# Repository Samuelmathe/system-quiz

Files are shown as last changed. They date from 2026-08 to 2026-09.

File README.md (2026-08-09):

# DMX Quiz Project (Arduino + Python)

Ce dossier contient :
- des **sketches Arduino** (`.ino`)
- 2 **logiciels Python** (interfaces GUI) pour piloter/configurer le système via USB (port série)

## Contenu

- **Arduino**
  - `megaf.ino` : sketch pour Arduino MEGA (DMX + logique de jeu ; plus de radio directe, voir `rf_nano_bridge.ino`)
  - `rf_nano_bridge.ino` : sketch pour **RF-Nano** (Nano + nRF24 intégrés) — pont radio nRF24 ↔ série vers le Mega ; seule carte du système avec un module radio
  - `buzzer_nano_equipe.ino` : sketch pour Arduino NANO (équipe)
  - `nano_son_final.ino` : sketch pour Arduino NANO (son)
  - `nano_animateur_final.ino` : sketch pour Arduino NANO (animateur)

- **Python**
  - `configuration/config_final_30.py` : outil de configuration (équipes / DMX / sync MEGA)
  - `interface/interface_30eq.py` : interface “quiz board” (scores/buzz + série)
  - `diagnostics/quiz_logger.py` : logger de diagnostic (écoute passive d'un port série dédié, en parallèle du logiciel de score — voir [Diagnostics](#diagnostics-quiz_loggerpy))

**Modes d’utilisation (sans PC / PC+Mega / PC+nano son)** : voir [MODES.md](MODES.md).

## Prérequis

- Python 3.9+ recommandé
- Arduino IDE (ou PlatformIO) pour compiler/téléverser les `.ino`

## Installation Python

Depuis la racine du projet :

```bash
python3 -m pip install --user -r requirements.txt
```

## Lancer les logiciels Python

Depuis la racine du projet :

```bash
python3 configuration/config_final_30.py
python3 interface/interface_30eq.py
```

## Fichiers créés automatiquement (configs)

- `configuration/config_final_30.py` lit/écrit : `configuration/config_quiz_pro.json`
- `interface/interface_30eq.py` lit/écrit : `interface/quiz_board_config.json`

Ces fichiers JSON sont créés automatiquement **à côté de chaque script**, ce qui rend le projet plus simple à partager et lancer depuis n'importe quel dossier.

## Sons (interface)

`interface/interface_30eq.py` essaie de charger des sons depuis le dossier `sounds/` **à côté du script** :
- `buzz.mp3` (buzz général / fallback)
- `victoire.mp3` (bonne réponse)
- `echec.mp3` (mauvaise réponse)
- `equipe_1.mp3` → `equipe_30.mp3` (sons spécifiques par équipe, optionnels)

Le dossier `sounds/` doit être **à côté du script** (ou à côté de l’exécutable si tu as “packagé” l’app).
Exemple attendu :

```
interface/
  interface_30eq.py
  sounds/
    buzz.mp3
    victoire.mp3
    echec.mp3
    equipe_1.mp3
    ...
    equipe_30.mp3
```

Si `pygame` n’est pas dispo (ou si les fichiers sont absents), l’interface fonctionne, mais sans sons.

## Diagnostics (`quiz_logger.py`)

Outil séparé du logiciel de score : il écoute en **passif** un port série de diagnostic
(un adaptateur USB-TTL dédié, branché en parallèle sur `PC_SERIAL`/`Serial3` du Mega —
aucun conflit avec le logiciel de score, qui utilise son propre adaptateur).

Il affiche le flux en direct, enregistre le log complet dans un fichier horodaté, et
génère un fichier résumé (durée de session, nombre de buzz, freezes/silences détectés,
redémarrages Mega détectés) pratique à partager pour du support/diagnostic à distance.

```bash
python3 diagnostics/quiz_logger.py
```

Un exécutable Windows est aussi généré automatiquement par GitHub Actions à chaque
modification de ce fichier (voir l'onglet *Actions* du dépôt).

## Linux : accès au port série Arduino

Si tu as une erreur de permission sur `/dev/ttyACM0` ou `/dev/ttyUSB0` :

```bash
sudo usermod -aG dialout $USER
```

Puis **déconnexion/reconnexion** (ou redémarrage) pour que le groupe soit pris en compte.

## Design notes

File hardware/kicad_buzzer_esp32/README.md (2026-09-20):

# Schéma de départ — Buzzer équipe (secours ESP32 / ESP-NOW)

`buzzer_equipe_esp32.kicad_sch` : même méthode que `../kicad_buzzer_nano/` (généré à partir du BOM, vérifié avec `kicad-cli sch erc` réel). 6 composants, 6 nets.

## L'ESP32 est représenté comme un connecteur générique 4 broches

Il n'existe pas de symbole KiCad standard pour la carte exacte commandée (ESP32 DevKit V1/ESP32-DevKitC-32 — trop de variantes de brochage différentes selon les fabricants). **U1** représente donc uniquement les 4 signaux réellement câblés sur ce PCB vers le module ESP32, pas les ~30 broches physiques :

| Broche U1 | Signal ESP32 | Usage (voir `esp32_buzzer_equipe.ino`) |
|---|---|---|
| 1 | GPIO4 | Bouton buzz |
| 2 | GPIO13 | IN du module vibreur |
| 3 | 5V / VIN | Alimentation |
| 4 | GND | Masse |

GPIO2 (LED embarquée) n'apparaît pas : elle est **interne au module ESP32 lui-même**, rien à router sur ce PCB pour elle.

## Avertissements ERC (28 au total)

| Type | Nombre | Normal ? |
|---|---|---|
| `endpoint_off_grid` | 12 | Cosmétique, sans conséquence électrique |
| `pin_not_connected` | 7 | À vérifier une fois dans l'interface — voir note ci-dessous |
| `lib_symbol_mismatch` | 7 | Cosmétique — `Outils > Mettre à jour les symboles depuis la bibliothèque` |
| `label_dangling` | 1 | **Normal en pratique** — ton propre projet `quizkicad/mega` (fait à la main) en a **71** du même genre. Pas un signe d'erreur de génération. |
| `power_pin_not_driven` | 1 | **Normal en pratique** — présent aussi dans `quizkicad/mega` (3 occurrences). |

Le `label_dangling` et plusieurs `pin_not_connected` concernent le réseau `BAT_PLUS`/`GND` autour de `BT1`/`J2`/`U1` — les coordonnées calculées correspondent bien aux broches réelles (vérifié), mais KiCad les affiche quand même comme non connectés. Comme pour la version Nano : cliquez l'étiquette et redéplacez-la légèrement pour forcer la reconnexion visuelle, ou ignorez si vous câblez de toute façon ce réseau en dur au routage du PCB.

## Rappel important

`ESPNOW_WIFI_CHANNEL` dans `esp32_buzzer_equipe.ino` doit rester identique à celui du hub (`esp32/esp32_bridge_server.ino`) — sans rapport avec ce schéma, mais à ne pas oublier au premier flash de la carte.

## PCB : placement compact + pistes routées

`buzzer_equipe_esp32.kicad_pcb` : empreintes placées, **et pistes routées** — même pipeline que la carte Nano (Freerouting en CLI headless + réimport KiCad + `kicad-cli pcb drc` réel), voir `../kicad_buzzer_nano/README.md` pour le détail du pipeline.

**Changements suite à ta relecture** :
- **Le texte-guide en sérigraphie a été retiré** — repères de composants standards uniquement (U1L, U1R, SW1...).
- **Carte bien plus compacte** : ~68×101mm au lieu de 130×145mm.
- **v3 : réduite encore à 65×50mm exactement**, pour correspondre au boîtier déjà conçu. U1L/U1R (les deux barrettes du module ESP32, 49mm de long chacune) ont dû être **pivotées à 90°** pour tenir dans cette largeur — leur entraxe réel (22,86mm) est inchangé, seule l'orientation sur la carte change, ça ne modifie rien au câblage ni au module qui s'enfiche dessus. Les 6 petits connecteurs (SW1, SW2, BATLED, J3, J2, BT1) sont serrés sur une seule rangée en bas de la carte, J2/J3 également pivotés à 90° pour gagner de la place en hauteur.
- Pas de keepout sur cette carte : pas de nRF24 ici, l'ESP-NOW utilise l'antenne intégrée à la puce ESP32 elle-même.
- **SW1, SW2, J2, J3 (connecteurs "fils volants") sont maintenant en CMS** (empreintes SMD), par choix explicite pour un assemblage machine (PCBA) chez le fabricant. Même numérotation de broche qu'avant. **Restent traversants** : U1L/U1R (le module ESP32 s'enfiche dessus) et **BT1**.
- **BT1 (batterie) est un vrai connecteur JST-PH** (`JST_PH_B2B-PH-K`, mâle, traversant) — même raisonnement que la carte Nano (voir son README) : la batterie a déjà une prise femelle sertie sur ses fils, et ce connecteur encaisse des cycles de branchement/débranchement qu'un pad CMS ne supporterait pas. Broche 1 = + (rouge), broche 2 = − (noir) — **vérifie la polarité sur ta batterie reçue**.
- **Nouveau : BATLED**, connecteur 2 broches (CMS) pour le module indicateur de niveau de batterie (4 LED) — même composant/câblage que la carte Nano, voir son README pour le détail.

**U1 est un vrai port femelle** : deux barrettes `PinSocket_1x19` (U1L/U1R, 38 broches au total, entraxe 22,86mm — la dimension déjà notée dans `hardware/boitier_buzzer_equipe.scad` pour ce module). Seules 4 des 38 positions physiques sont câblées (GPIO4, GPIO13, VIN, GND) ; les 34 autres sont présentes uniquement pour que le module s'enfiche mécaniquement.

⚠️ **Brochage à vérifier sur le module reçu avant de souder** : contrairement à la carte hub (ESP32 DevKit V1 30 broches, un modèle de référence unique et confirmé par toi), les cartes ESP32 38 broches existent en plusieurs variantes de brochage chez différents fabricants. J'ai utilisé la disposition générique la plus courante ("style NodeMCU-32S", vérifiée sur https://www.espboards.dev/esp32/esp32-38pin-devkit-generic/) : broche réelle 32 = GPIO4, broche 15 = GPIO13, broche 19 = VIN, broche 14 = GND. **Compare ces numéros avec les repères imprimés sur ton module avant de souder** — si ça ne correspond pas, il suffit de déplacer les 4 fils, la carte elle-même n'a pas besoin d'être refaite.

- Aperçu : `apercu_pcb.png`.

**Résultat (v3, 65×50mm)** : **0 violation de clearance, 0 élément non connecté**. DRC final : 19 avertissements, tous cosmétiques — `lib_footprint_mismatch` (5, comme d'habitude), `silk_overlap` (1, texte de référence U1R qui chevauche légèrement son propre contour après la rotation à 90°), et `silk_over_copper` (13, des pistes routées passent juste sous la sérigraphie de J2/J3 — carte très dense, aucun impact électrique, juste un risque que l'encre sérigraphie ne s'imprime pas parfaitement à ces endroits précis). Un `track_dangling` initial (résidu d'autorouter, un stub B.Cu redondant en doublon d'un chemin déjà assuré côté F.Cu) identifié et supprimé après vérification de la topologie réelle — **0 track_dangling restant**.

## Prochaine étape

Ouvre le PCB dans KiCad, relis le routage à l'œil, puis passe aux fichiers de fabrication (Gerbers).

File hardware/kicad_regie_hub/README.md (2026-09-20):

# Schéma de départ — Régie/Hub (adaptateur Mega + ESP32 + nRF24)

`regie_hub_mega_esp32.kicad_sch` : même méthode que les deux cartes buzzer (généré, **vérifié avec `kicad-cli sch erc` réel**). 11 composants, 14 nets.

## ⚠️ Correction : broches VCC/GND du nRF24 inversées, module PA+LNA (2×4)

Même correction que sur la carte buzzer Nano (voir `../kicad_buzzer_nano/README.md` pour le détail complet) : **J_NRF avait VCC en broche 1 et GND en broche 2 — inversé par rapport à la vraie numérotation** (broche 1 = GND, broche 2 = VCC), vérifié contre 3 sources indépendantes. Corrigé partout. Ton module confirmé étant un **nRF24L01+PA+LNA** (2×4 broches), l'empreinte J_NRF est passée de `PinSocket_1x08` à `PinHeader_2x04` (connecteur **mâle** — le module a lui-même des ports femelles, donc c'est la carte qui doit porter les broches mâles).

## Ce que cette carte est (et n'est pas)

**Ce n'est PAS un shield Mega complet.** Le shield DMX (`quizkicad/mega`, projet séparé, non touché) s'empile déjà directement sur la Mega. Cette carte-ci est un **petit adaptateur** qui porte l'ESP32 + le nRF24 + l'électronique entre les deux, relié à la Mega par seulement **6 fils** :

| Broche J_MEGA | Signal | Vers la Mega |
|---|---|---|
| 1 | TX2 (5V) | Mega pin 16 |
| 2 | RX2 | Mega pin 17 |
| 3 | TX1 (5V) | Mega pin 18 |
| 4 | RX1 | Mega pin 19 |
| 5 | 5V | Sortie régulateur onboard de la Mega |
| 6 | GND | Masse commune |

⚠️ **[FIX] Broches 3/4 déplacées de Mega Serial3 (pins 14/15) vers Mega Serial1 (pins 18/19)** : en vérifiant le câblage réel avec Samuel, Serial3 était déjà utilisé par le shield DMX (mal aiguillé côté firmware, corrigé dans `megaf.ino`) et doit rester dédié au câble TTL PC (scripts Python) comme lien de secours simultané au WiFi. Serial1 était complètement libre sur la Mega — voir `megaf.ino` et `esp32/esp32_bridge_server.ino` pour le détail complet.

**Alimentation** : pas de batterie sur cette carte — confirmé par toi : "on branche le mega [secteur] mais le reste des modules sera alimenté [par lui]". Le 5V vient du régulateur déjà présent sur la Mega.

## Pourquoi un pont diviseur et pas un module convertisseur de niveau logique

Tu as mentionné un "convertisseur logique" entre les RX/TX de la Mega et de l'ESP32. J'ai utilisé le **pont diviseur 1kΩ/2kΩ** à la place d'un module dédié — ce n'est pas un raccourci, c'est la solution **déjà documentée et déjà validée sur ce projet** (`cl.md` section 3.3, schéma dans `docs/APK_HYBRIDE_GUIDE.md`) pour exactement ces deux liaisons série. Réutiliser une solution qui marche déjà coûte moins cher et évite d'introduire une dépendance à un nouveau module non testé sur ce projet.

- **R1/R2** : diviseur sur Mega TX2 (5V) → ESP32 RX1 (3,3V) — lien Jeu.
- **R3/R4** : diviseur sur Mega TX1 (5V) → ESP32 RX2 (3,3V) — lien Config EEPROM (déplacé depuis TX3, voir note ci-dessus).
- **Pas de diviseur dans l'autre sens** (ESP32 TX → Mega RX) : déjà documenté que le 3,3V est lu comme HIGH par les entrées 5V de la Mega, connexion directe.

## Pourquoi un régulateur dédié au nRF24 (pas le 3V3 de l'ESP32)

Demandé : "un régulateur pour esp32" + "tout ce qui va avec ces composants pour un meilleur rendement". Plutôt que d'alimenter le nRF24 depuis la broche 3V3 embarquée de l'ESP32 (qui partage déjà la charge du Wi-Fi — creux de tension possible, cause connue d'instabilité nRF24, historique documenté sur ce projet), **U_REG** est un module régulateur 3,3V dédié rien que pour le nRF24, avec son propre découplage (C2, C3 — le condensateur 10-100µF déjà exigé par `cl.md` pour le nRF24).

## Avertissements ERC (36 au total)

Même profil que les deux cartes buzzer, déjà expliqué en détail dans `../kicad_buzzer_nano/README.md` — normal en pratique KiCad (comparé contre `quizkicad/mega`, ton propre projet fait à la main) :

| Type | Nombre | Normal ? |
|---|---|---|
| `endpoint_off_grid` | 20 | Cosmétique |
| `lib_symbol_mismatch` | 9 | Cosmétique — `Outils > Mettre à jour les symboles depuis la bibliothèque` |
| `pin_not_connected` | 4 | 2 attendus (3V3 onboard ESP32 et IRQ nRF24, non utilisés — no-connect posé), 2 liés au réseau GND (nuance ERC normale, voir README buzzer) |
| `no_connect_dangling` | 2 | Marqueurs "pas de connexion" légèrement décalés — à recaler d'un clic |
| `power_pin_not_driven` | 1 | Normal sur un réseau GND (également présent dans `quizkicad/mega`) |

## PCB : placement compact + pistes routées

`regie_hub_mega_esp32.kicad_pcb` : empreintes placées, **et pistes routées** — même pipeline que les deux cartes buzzer (Freerouting en CLI headless + réimport KiCad + `kicad-cli pcb drc` réel), voir `../kicad_buzzer_nano/README.md` pour le détail (y compris le mécanisme de keepout, identique ici).

**Changements suite à ta relecture** :
- **Le texte-guide en sérigraphie a été retiré** — repères de composants standards uniquement (J_MEGA, U_ESP32L/R, J_NRF, U_REG, R1-R4, C1-C3), pas de paragraphe d'instructions gravé sur la carte.
- **Carte bien plus compacte** : ~137×85mm au lieu de 185×145mm.
- **C3 (découplage nRF24) encore rapproché de J_NRF** (~12mm, contre 25mm dans la toute première version).
- **Zone sans cuivre sous le nRF24** : même mécanisme keepout que la carte Nano (voir son README pour le détail de la vérification), placé en presqu'île contre le bord droit pour ne bloquer aucun chemin de routage.
- **U_ESP32 est un vrai port femelle** : deux barrettes `PinSocket_1x15` (U_ESP32L/R, 30 broches, entraxe 15,24mm). Seules 11 des 30 positions physiques sont câblées ; les 19 autres sont présentes pour que le module s'enfiche mécaniquement. Brochage : **DOIT ESP32 DevKit V1, 30 broches** — exactement le modèle confirmé commandé, design de référence unique et bien plus standardisé que les clones 38 broches (vérifié sur https://www.espboards.dev/esp32/esp32doit-devkit-v1/).
- **J_NRF (nRF24) est un connecteur MÂLE 2×4** (`PinHeader_2x04`) — le module a des ports femelles dessus, donc la carte porte les broches mâles. 1=GND, 2=VCC, puis CE/CSN/SCK/MOSI/MISO/IRQ. ⚠️ **Vérifie les repères sur ton module avant de souder**, aucun standard universel pour les variantes PA+LNA.
- **R1-R4 et C1-C3 sont maintenant en CMS** (`R_0805`/`C_0805`), par choix explicite pour un assemblage machine (PCBA) chez le fabricant. Même numérotation de broche qu'avant. **Restent traversants** : J_MEGA, U_ESP32L/R et J_NRF (connecteurs de liaison/modules enfichables, pas adaptés au CMS).
- Aperçu : `apercu_pcb.png`.

**Résultat** : 78 connexions (14 nets), **0 violation de clearance, 0 élément non connecté**, 5 vias placées, keepout respecté (0 piste dedans, vérifié par script). DRC final : 12 avertissements, tous `lib_footprint_mismatch` (cosmétique). 4 `track_dangling` initiaux (résidus d'autorouter) identifiés et supprimés après vérification de la topologie réelle — **0 track_dangling restant**.

**C3 (découplage nRF24) rapproché de J_NRF** : le placement initial mettait C3 à 25mm de J_NRF (net `NRF_VCC_DEDIE`, qui relie aussi C2 et U_REG — ce n'est pas un simple lien à 2 broches). Trop loin pour un découplage propre à 2,4GHz. C3 a été repositionné à 12mm de J_NRF (`(152,20)` au lieu de `(165,20)`) et la carte entièrement re-routée : la piste J_NRF↔C3 est maintenant un tronçon direct et court, visible sur `apercu_pcb.png`.

## Prochaine étape

Ouvre le PCB dans KiCad et relis le routage à l'œil, puis passe aux fichiers de fabrication (Gerbers) — en particulier bien respecter les recommandations `cl.md` (VCC nRF24 en 3,3V uniquement jamais 5V, GND commun).

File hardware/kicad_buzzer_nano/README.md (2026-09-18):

# Schéma de départ — Buzzer équipe (Nano + nRF24)

`buzzer_equipe_nano.kicad_sch` : schéma généré à partir du BOM (`../../docs/BOM_BUZZER_EQUIPE.md`), **vérifié avec KiCad lui-même** (`kicad-cli sch erc`, format v9.0) — pas juste du texte non testé. 8 composants, 12 nets connectés (alimentation, bouton, module vibreur, nRF24 sur SPI matériel).

## ⚠️ Correction : broches VCC/GND du nRF24 inversées dans une version précédente

En répondant à ta question "le nrf24 c'est sur une ligne ?", j'ai vérifié le brochage du module nRF24 contre 3 sources indépendantes (components101.com, lastminuteengineers.com, doc générale nRF24L01+) et découvert que **J1 avait VCC en broche 1 et GND en broche 2 — c'est l'inverse** de la vraie numérotation (broche 1 = GND, broche 2 = VCC ; la broche 1 est d'ailleurs toujours la pastille carrée sur cette empreinte, et GND est documenté comme "identifiable par son marquage carré" sur les vrais modules). Corrigé partout : schéma, PCB, ce README. Si tu avais déjà commencé à câbler en suivant l'ancienne version, vérifie/corrige avant de mettre sous tension.

Tu as aussi confirmé que ton module est un **nRF24L01+PA+LNA** (longue portée, antenne externe) — ses 8 broches sont sur un connecteur **2×4**, pas 1×8 comme le module standard. L'empreinte J1 a été changée en conséquence (voir section PCB ci-dessous).

## Comment l'ouvrir

Ouvrez `buzzer_equipe_nano.kicad_sch` directement dans KiCad (File > Open). Aucun `.kicad_pro` fourni — KiCad vous proposera d'en créer un, acceptez.

## À faire en premier en l'ouvrant

L'ERC (`Inspecter > Vérification des règles électriques`) remonte 72 avertissements. La plupart sont normaux, mais trois méritent un coup d'œil :

| Avertissement | Nombre | À faire |
|---|---|---|
| `pin_not_connected` | 30 | **Normal** — la plupart des broches du Nano (A0-A7, D0/D1/D3/D4/D6/D7/D8...) ne sont pas utilisées par ce boîtier. Ignorer, ou ajouter des drapeaux "Pas de connexion" si vous voulez un ERC propre. |
| `lib_symbol_mismatch` | 12 | Cosmétique — mes copies embarquées des symboles (GND, +3V3, Battery_Cell) diffèrent légèrement de la bibliothèque système. `Outils > Mettre à jour les symboles depuis la bibliothèque` règle ça en un clic. |
| `endpoint_off_grid` | 19 | Cosmétique — mes coordonnées calculées ne tombent pas toujours pile sur la grille par défaut de KiCad. Sans conséquence électrique, juste esthétique. |
| `label_dangling` | 3 | **Normal en pratique** — `BAT_PLUS`, `NRF_SCK`, `VCC_5V_SW` : l'étiquette semble pile sur la bonne broche (vérifié par calcul), KiCad la signale quand même comme non connectée. J'ai vérifié : **ton propre projet `quizkicad/mega`** (fait à la main dans KiCad, pas généré) a **71** avertissements du même genre — c'est une nuance ERC courante, pas un signe d'erreur de génération. Cliquez l'étiquette et redéplacez-la légèrement si vous voulez un ERC propre, sinon ignorez. |
| `no_connect_dangling` | 1 | Le marqueur "pas de connexion" sur la broche IRQ du module nRF24 (non utilisée par le firmware) est légèrement décalé — à recaler d'un clic sur la broche. |
| `power_pin_not_driven` / `pin_not_driven` | 4 + 3 | Également présent dans `quizkicad/mega` (3 occurrences de `power_pin_not_driven`) — nuance ERC normale sur les réseaux GND, pas un bug. |

## PCB : placement compact + pistes routées

`buzzer_equipe_nano.kicad_pcb` : empreintes placées, **et pistes routées** — 2 couches (F.Cu/B.Cu), autoroutées avec [Freerouting](https://freerouting.app/) (outil open source dédié, pas un routage "deviné" à la main par moi) puis réimportées dans KiCad, le tout vérifié avec `kicad-cli pcb drc` réel.

**Changements suite à ta relecture** :
- **Le texte-guide en sérigraphie a été retiré** — ça n'a pas sa place gravé sur un vrai circuit fabriqué. Il ne reste que les repères de composants standards (A1L, J1, C1...), comme sur n'importe quelle carte.
- **Carte bien plus compacte** : ~90×100mm au lieu de 125×145mm — composants resserrés, plus d'espace perdu.
- **C1 (découplage nRF24) déplacé juste à côté de J1** (~10-12mm au lieu de ~30mm) pour un découplage propre.
- **Zone sans cuivre sous le nRF24** : un keepout (pistes/vias/plans interdits, sur les deux couches F.Cu et B.Cu) couvre l'espace où le corps/l'antenne du module PA+LNA se trouve une fois enfiché — pour ne pas mettre de cuivre sous l'antenne. Positionné en "presqu'île" contre le bord droit de la carte (rien ne route à travers), pas collé sur J1 des deux côtés — une première tentative avait bloqué le routeur (8 pistes bloquées après 100+ passes) en enfermant le connecteur ; corrigé en laissant un côté totalement ouvert. **Vérifié réellement respecté par Freerouting** (pas juste accepté par KiCad) via un test dédié où un keepout bloquant délibérément le seul chemin entre 2 pastilles a fait router 0 piste par l'autorouteur — preuve qu'il n'était pas ignoré. Taille/position à vérifier/ajuster dans KiCad selon les dimensions réelles de ton module.
- **Le Nano est représenté par de vrais ports femelles** : deux barrettes `PinSocket_1x15` séparées (A1L = broches réelles 1-15, A1R = 16-30, espacées de 15,24mm comme sur un vrai Nano). Le Nano s'enfiche dessus, rien à souder sur le module lui-même.
- **J1 (nRF24) est un connecteur MÂLE 2×4** (`PinHeader_2x04`) — corrigé après que tu as précisé que le module lui-même a des ports femelles dessus, donc c'est la carte qui doit porter des broches mâles pour que le module s'enfiche dessus (logique inverse de A1L/A1R où c'est le Nano qui a des broches mâles). Broches 1=GND et 2=VCC sur la 1ère rangée, puis CE/CSN, SCK/MOSI, MISO/IRQ — ordre le plus souvent publié pour ce type de module, mais **aucun standard universel n'existe pour les variantes PA+LNA**. ⚠️ **Vérifie les repères imprimés sur ton module avant de souder.**
- **C1 et les connecteurs "fils volants" (SW1, SW2, J2, J3) sont maintenant en CMS** (empreintes SMD — `C_0805`, `PinSocket_..._SMD`), par choix explicite pour un assemblage machine (PCBA) chez le fabricant plutôt qu'à souder toi-même. Même numérotation de broche que les anciennes versions traversantes, rien d'autre n'a changé côté câblage. **Restent traversants** : A1L/A1R (Nano), J1 (nRF24) — headers de modules enfichables, pas adaptés au CMS — et **BT1**, voir point suivant.
- **BT1 (batterie) est maintenant un vrai connecteur JST-PH** (`JST_PH_B2B-PH-K`, mâle, traversant) au lieu de simples pastilles. Les batteries LiPo standards arrivent avec une prise JST-PH **femelle** déjà sertie sur leurs fils — la batterie se branche donc directement, rien à couper ni souder sur ses fils. Volontairement resté traversant (pas de version CMS) : ce connecteur encaisse des cycles répétés de branchement/débranchement, un pad CMS se décollerait à l'usage. Broche 1 = + (fil rouge), broche 2 = − (fil noir) — convention quasi universelle sur les batteries LiPo JST-PH, mais **vérifie la polarité sur ta batterie reçue** avant de brancher.
- **Nouveau : BATLED**, connecteur 2 broches (CMS) pour le module indicateur de niveau de batterie (4 LED, 25/50/75/100% — module "1S lithium battery capacity indicator", vérifié via handsontec.com). Branché directement en parallèle sur la batterie (même net que BT1 : broche 1 = B+, broche 2 = B-, ~5mA, toujours actif, pas de bouton). Voir `../../docs/BOM_BUZZER_EQUIPE.md`.
- Aperçu : `apercu_pcb.png`.

**Pipeline utilisé** : `pcbnew.ExportSpecctraDSN()` → `freerouting.jar` (mode CLI headless, `-mp 20`) → `pcbnew.ImportSpecctraSES()` → `kicad-cli pcb drc`. 74 connexions, **0 violation de clearance, 0 élément non connecté**, keepout respecté (0 piste dedans, vérifié par script).

**DRC final** : 5 avertissements, tous `lib_footprint_mismatch` (cosmétique, se corrige avec `Outils > Mettre à jour les empreintes depuis la bibliothèque`) — **0 track_dangling** dès le premier autoroutage cette fois.

**À vérifier toi-même avant fabrication** : largeur de piste/clearance par défaut de KiCad (pas de netclass personnalisée définie ici) — correcte pour du signal logique, mais à confirmer sur les nets d'alimentation (`VCC_5V_SW`, `GND`) selon le courant réel du vibreur.

## Prochaine étape

Ouvre `buzzer_equipe_nano.kicad_pcb` dans KiCad et relis le routage à l'œil (largeurs de piste, trajets) avant de passer aux fichiers de fabrication (Gerbers).

La version ESP32 (secours équipe) est dans `../kicad_buzzer_esp32/`, même méthode.

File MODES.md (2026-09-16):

# Trois modes d’utilisation — scores & sons (Quiz Board)

Ce document décrit les **trois configurations** possibles entre **Mega** (DMX + logique jeu, `megaf.ino`), **RF-Nano** (pont radio nRF24 ↔ série, `rf_nano_bridge.ino`), **nano son** (DFPlayer + radio), et le **logiciel** `interface/interface_30eq.py` (scores, sons PC, port série).

**Architecture radio (depuis la migration RF-Nano)** : le Mega n’a plus de module nRF24 branché directement (c’était la source d’un gel intermittent diagnostiqué en conditions réelles — connexion physique fragile vers la puce radio). Toute la réception nRF24 (équipes, animateur) et l’émission vers le nano son sont désormais assurées par une carte **RF-Nano** dédiée (Nano + nRF24 intégrés d’usine), reliée au Mega par une simple liaison série filaire (`Serial2`, 19200 bauds). Le Mega envoie/reçoit de simples lignes texte (`BUZZ:n`, `CMD:99`, `SON:200:n`…) au RF-Nano, qui traduit ça en paquets radio et inversement. Cette isolation protège la logique de jeu/DMX : même si le RF-Nano a un problème radio, le Mega continue de tourner.

**Règle matérielle (PC)** : le PC n’est branché en série qu’**à une seule carte à la fois** — soit la **Mega** (TTL / USB), soit le **nano son** (USB), **jamais les deux en même temps**. En mode 3, la Mega reste alimentée pour le DMX et le pilotage du RF-Nano, mais **sans** câble série vers le PC ; tout passe par le nano son (USB).

---

## Vue d’ensemble

| Mode | PC branché ? | Où vont les sons ? | Scores / interface |
|---|---|---|---|
| **1 — Sans PC** | Non | **DFPlayer** sur le nano son (carte SD, radio depuis la Mega) | Aucun logiciel |
| **2 — PC sur la Mega** | Oui, **port série TTL** de la Mega (`Serial3` / dongle USB‑UART) | **PC** (`sounds/*.mp3` via pygame) ; le nano son en salle est **optionnel** | Oui : buzz, points, VALIDER/FAUX, `CMD_SENT:` |
| **3 — PC sur le nano son** | Oui, **USB du nano son** | **PC** si mode **AUDIO_PC** (HP du DF débranché ou inutilisé) ; sinon **DFPlayer** si **AUDIO_DF** | Oui : le logiciel détecte le nano (`WHO` → `READY_NANO_SON`) |

---

## Mode 1 — Sans ordinateur

- La **Mega** gère la logique du jeu et le DMX ; elle reçoit les buzz/commandes animateur du **RF-Nano** par liaison série filaire, et lui envoie en retour les ordres **son** (`SON:200:n`, `SON:201:0`, `SON:202:0`) par la même liaison.
- Le **RF-Nano** retransmet ces ordres son en radio vers le **nano son** (pipe `00002`, payload `200` / `201` / `202`) — exactement le même paquet qu’avant, seule l’origine a changé (RF-Nano au lieu de la Mega directement).
- Le **nano son** joue les fichiers sur la **carte microSD** du DFPlayer (dossier `mp3/` sur la carte, ex. `0101.mp3` pour l’équipe 1, repli `0001.mp3`).
- **Pas** de fichier `equipe_1.mp3` sur le PC : tout passe par la convention **DF** (`0101` … `0130`).

---

## Mode 2 — PC branché sur la **Mega** (usage principal)

- Câble **USB‑UART** sur le port prévu pour le PC (souvent **TX3/RX3** de la Mega, voir commentaires dans `megaf.ino`).
- Le logiciel reçoit :
  - **`BUZZ:n`** quand une équipe buzze ;
  - **`CMD_SENT:RESET_ALL`** / **`CMD_SENT:RELANCE_PARTIEL`** quand l’animateur utilise les **boutons physiques** (nano animateur → Mega).
- Les **sons** passent par le dossier **`sounds/`** à côté du script : `buzz.mp3`, `victoire.mp3`, `echec.mp3`, et surtout **`equipe_1.mp3` … `equipe_30.mp3`** pour le buzz par équipe (priorité sur `buzz.mp3`).
- Le **nano son** peut rester en salle pour la même piste radio ; si le PC joue déjà les sons, évite d’avoir **deux** enceintes au même moment (ou baisse le volume d’un des deux chemins).

---

## Mode 3 — PC branché sur le **nano son** (USB)

- Dans le logiciel, choisis le **COM du nano son**. Après connexion, le programme envoie `WHO` : si la réponse contient **`READY_NANO_SON`**, le mode **nano** est actif.
- **Sons sur le PC (`AUDIO_PC`, défaut à la connexion)**  
  - Le nano **ne joue pas** sur le DF pour le buzz : il renvoie **`FWD_SON:200:N`** au PC pour que **pygame** joue (tu peux **débrancher le HP** du module DF pour n’entendre que le PC).
  - **Buzz** : `FWD_SON:200` = même traitement qu’un **`BUZZ:`** en mode 2 (état BUZZÉ, `equipe_N.mp3` si présent).
  - **Valider / refuser** (animateur → Mega → radio **201** / **202** → nano) : le nano envoie **`CMD_SENT:RESET_ALL`** / **`CMD_SENT:RELANCE_PARTIEL`** sur l’USB → **points et état** comme en mode 2, sans second câble vers la Mega.
- **Sons sur la carte SD (`AUDIO_DF`)**  
  - Décoche l’option « sons sur le PC » dans l’interface (ou envoi série `AUDIO_DF`) : le nano rejoue sur le **DFPlayer** comme en mode 1 ; fichiers **`mp3/0101.mp3`** … **`0130.mp3`** (équivalent `equipe_N` côté PC).

### Relais série depuis le PC (nano USB)

- Le logiciel peut envoyer **`RESET_ALL`** / **`RELANCE_PARTIEL`** au nano : le nano **réémet** les commandes radio vers les buzzers (même format que la Mega), utile si la Mega n’est **pas** sur le port PC mais toujours alimentée pour le DMX.

### Fichier de config

- `interface/quiz_board_config.json` (à côté du script) peut contenir entre autres :
  - **`points_au_buzz`** : points ajoutés au **moment du buzz** (0 = désactivé ; la bonne réponse ajoute encore la valeur « PTS » choisie dans l’interface).

---

## Correspondance des noms de fichiers (équipe 1, …)

| Équipe affichée | PC (`sounds/`) | Carte SD DFPlayer (`mp3/` sur la carte) |
|---|---|---|
| 1 | `equipe_1.mp3` | `0101.mp3` |
| N | `equipe_N.mp3` | `01NN.mp3` dans le dossier **`mp3/`** à la racine de la carte (ex. équipe 12 → `0112.mp3`). Le sketch utilise **`playMp3Folder(NNN)`** (commande 0x12) : **101** = fichier **`0101.mp3`**, **1** = **`0001.mp3`** — pas la commande `play()` qui suit l’ordre des fichiers sur la carte. |

La Mega envoie toujours le **numéro d’équipe 1…30** dans le payload radio **200** ; le nano son et le logiciel s’en servent pour choisir la piste ou le fichier.

---

## Fiabilité radio RF-Nano ↔ nano son (nRF24L01)

- **Même canal et adresse** : canal **108**, pipe **`00002`** pour les paquets `SonPayload`.
- **Buzz (200)** : le RF-Nano envoie une rafale de copies espacées de quelques ms (`envoyerSon()`/`updateRadioSonAsynchrone()` dans `rf_nano_bridge.ino`, portées depuis l’ancien `megaf.ino`) avec un **numéro de séquence** (`seq`) ; le nano met les paquets en **file** et **dédoublonne** par `cmd`+`team`+`seq`. DFPlayer : lecture **immédiate** si la piste équipe a déjà réussi une fois, sinon test erreur en fond.
- **Victoire / échec (201 / 202)** : même principe de rafale + dédoublonnage par `seq`.
- **Bonnes pratiques** : alimentation stable (condensateur près du nRF24), antennes correctes, distance raisonnable ; le **250 kbps** aide la portée.

## Fiabilité liaison Mega ↔ RF-Nano (série filaire)

- **`Serial2` sur la Mega (RX2=17, TX2=16)**, **19200 bauds**, GND commun obligatoire.
- Protocole texte simple, une commande par ligne : `BUZZ:n`, `CMD:99`/`CMD:88`, `SON:cmd:team`.
- Le RF-Nano dédoublonne aussi les commandes animateur par `seq` (évite qu’un accusé de réception radio perdu ne fasse rejouer plusieurs fois le son/flash pour un seul appui bouton).
- **Attention en développement** : les broches D0/D1 du RF-Nano sont partagées avec l’USB — débrancher le fil vers la Mega pour reprogrammer/déboguer via USB.

---

## Rappel câblage série (un seul port PC)

| Mode | Câble PC | Lignes reçues par le Quiz Board |
|---|---|---|
| **2 — Mega** | TTL Mega (Serial3) | `BUZZ:n`, `CMD_SENT:…` |
| **3 — Nano son** | USB nano son | `FWD_SON:200:n` (buzz), `CMD_SENT:…` (valider / faux via radio) |

Pas de branchement simultané Mega + nano son sur le même PC.

Pour lancer l’interface et les prérequis Python, voir le [README](README.md).

---

## Architecture de secours : équipes/animateur en ESP32 + ESP-NOW (sans nRF24)

**Uniquement pour l'architecture ESP32 hub** (`esp32/esp32_bridge_server.ino`, qui remplace le RF-Nano). Ne concerne pas `rf_nano_bridge.ino` / `megaf.ino`.

Historique de fiabilité nRF24 sur ce projet (gel intermittent diagnostiqué puis corrigé, bug de stress-test) : si un module nRF24 pose problème sur site, `esp32_buzzer_equipe.ino` et `esp32_animateur.ino` permettent de remplacer **un boîtier à la fois** (Nano+nRF24 → ESP32) sans toucher au hub ni aux autres boîtiers.

- **Un seul hub, deux transports simultanés** : le hub écoute nRF24 **et** ESP-NOW en même temps (`traiterMessageRadio()` dans `esp32_bridge_server.ino`), avec le **même** `RadioMsg{kind,value,seq}`, le **même** dédoublonnage par `seq`, la **même** fenêtre d'arbitrage de 50ms. Une équipe peut être en nRF24 pendant qu'une autre est en ESP-NOW.
- **Canal Wi-Fi fixe obligatoire** (`ESPNOW_WIFI_CHANNEL`, 6 par défaut) : à garder identique dans les **trois** fichiers (`esp32_bridge_server.ino`, `esp32_buzzer_equipe.ino`, `esp32_animateur.ino`). ESP-NOW exige que l'émetteur et le récepteur soient sur le même canal ; le hub le fixe via `WiFi.softAP(..., ESPNOW_WIFI_CHANNEL)`, changez cette valeur partout si le canal 6 est pollué sur le lieu de l'événement.
- **Broadcast, aucun appairage MAC** : plus simple à déployer en urgence (remplacer un boîtier en quelques secondes), au prix de l'absence d'accusé de réception matériel pour le broadcast (contrairement au nRF24 avec `setAutoAck`). Compensé par une **rafale de 4 copies** espacées de 12ms (`BURST_COUNT`/`BURST_GAP_MS`), même principe que la rafale son déjà utilisée dans ce projet — le hub dédoublonne par `seq`, donc les copies en trop ne créent jamais de buzz en double.
- **Consommation** : le Wi-Fi tire plus de courant que le nRF24 — moins d'autonomie si les boîtiers équipes sont sur pile plutôt que secteur/USB.

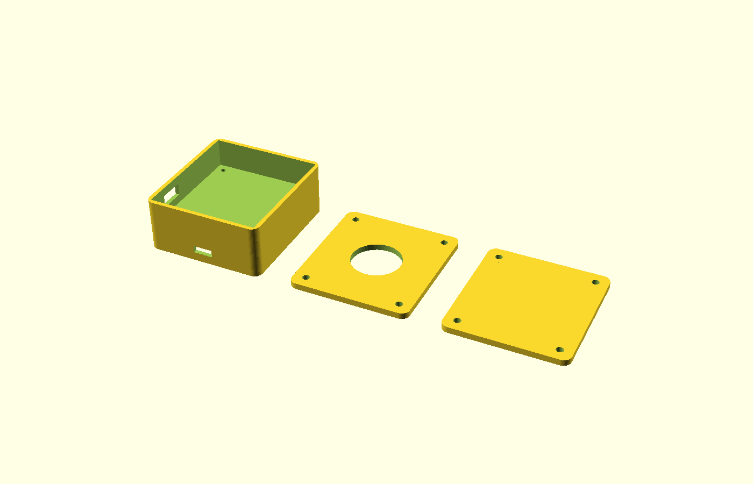
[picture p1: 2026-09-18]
hardware/apercu_variante_esp32.png

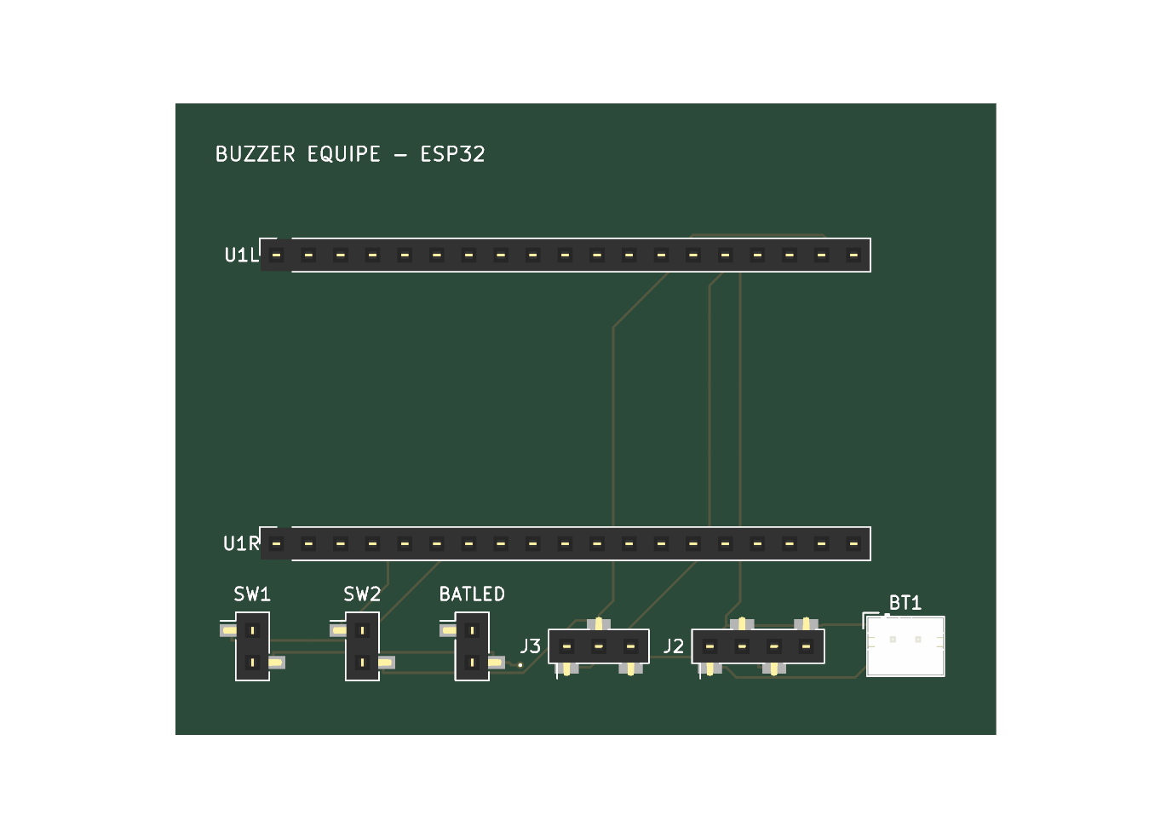
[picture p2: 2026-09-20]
hardware/kicad_buzzer_esp32/apercu_pcb.png

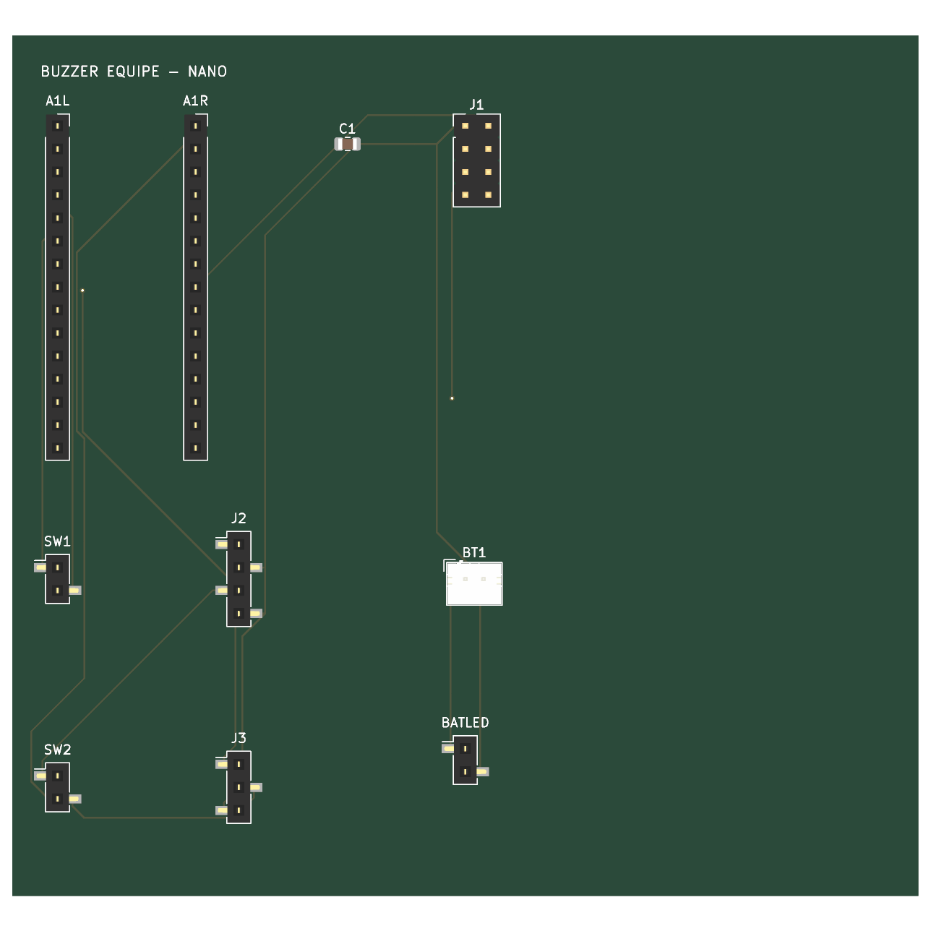
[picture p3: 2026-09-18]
hardware/kicad_buzzer_nano/apercu_pcb.png

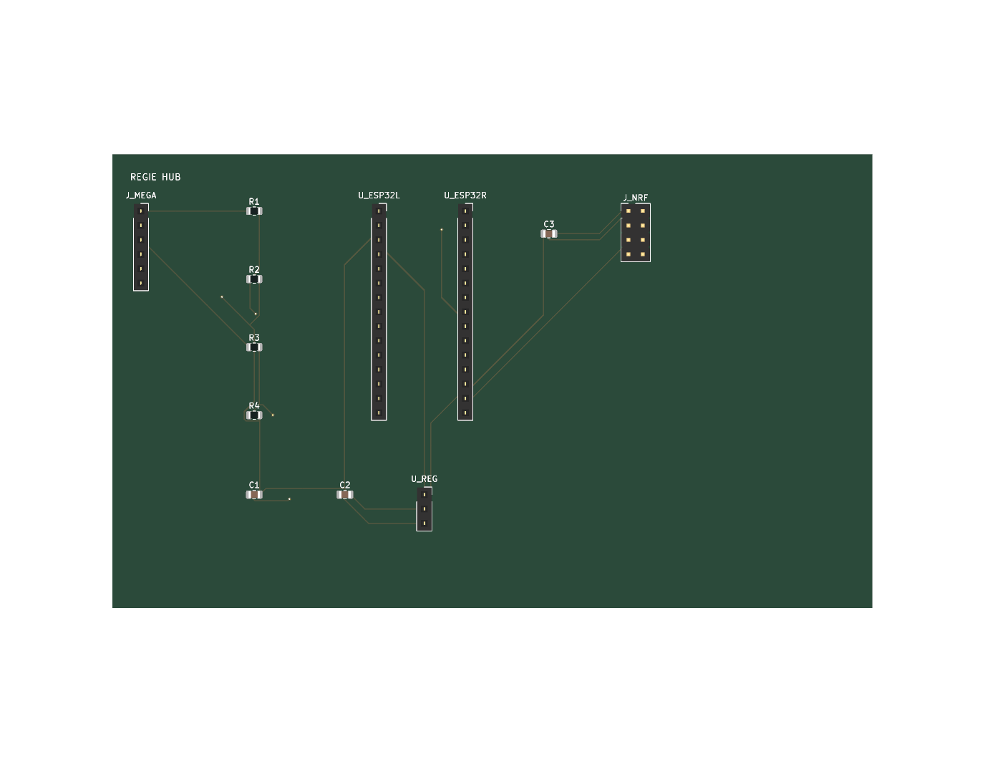
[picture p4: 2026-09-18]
hardware/kicad_regie_hub/apercu_pcb.png

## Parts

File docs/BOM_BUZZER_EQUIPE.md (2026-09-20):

# BOM & brochage — Boîtiers buzzer équipe (Nano+nRF24 et ESP32)

Référence pour démarrer le schéma KiCad des deux cartes. Basé sur le câblage déjà utilisé par le firmware (`buzzer_nano_equipe.ino` / `esp32_buzzer_equipe.ino`) — **aucun changement de code nécessaire**, seul le matériel autour est nouveau.

---

## ⚠️ Règle d'achat obligatoire : connecteur pré-câblé sur CHAQUE module

Les cartes PCBA sont livrées **directement au client**, pas à Samuel — il n'y a aucune étape intermédiaire où quelqu'un peut sertir/souder un connecteur avant l'envoi. Résultat : **le client ne doit jamais avoir besoin d'un fer à souder**, donc chaque module externe (pas juste la batterie) doit être acheté dans sa version **déjà équipée d'une prise compatible** sur ses fils, jamais en fils nus.

Chaque ligne concernée ci-dessous est marquée **🔌 connecteur pré-câblé obligatoire à l'achat**. Si un fournisseur ne propose vraiment aucune version pré-câblée pour l'un de ces éléments, c'est le seul point qui devra être signalé explicitement au client comme exception (fer à souder nécessaire) — à éviter autant que possible.

---

## Vibreur : module tout fait (IN / VCC / GND)

Confirmé : les vibreurs utilisés sont des **modules** à 3 broches (IN / VCC / GND), pas des moteurs nus. Le transistor de commande, la résistance de base et la diode de roue libre sont déjà intégrés sur le petit PCB du module — pas besoin de les reproduire sur la carte buzzer.

🔌 **Connecteur pré-câblé obligatoire à l'achat** — chercher une version du module avec un connecteur (JST/Dupont) déjà serti sur les 3 fils IN/VCC/GND, pas des fils nus à souder. Moins garanti que pour une batterie LiPo (module bon marché, souvent vendu en fils nus) — vérifier la fiche produit avant d'acheter, sinon prévoir de sertir soi-même avant tout envoi au client.

Câblage simplifié (identique sur les deux cartes) :

```
   GPIO (moteurPin) ──▶ IN
   5V (sortie boost) ──▶ VCC
   GND                ──▶ GND
```

`digitalWrite(moteurPin, HIGH/LOW)` pilote directement l'entrée IN du module, qui fait la commutation en interne. Si jamais vous passez un jour à un moteur nu (sans module), remettre un étage transistor+résistance+diode comme d'habitude sur ce type de charge inductive — mais ce n'est pas le cas ici.

---

## Bloc alimentation (commun aux deux cartes)

| Élément | Réf. type | Rôle |
|---|---|---|
| Batterie LiPo 1S 3,7V | Voir capacité par carte ci-dessous — 🔌 **connecteur JST-PH pré-serti obligatoire à l'achat** (standard sur la quasi-totalité des batteries hobby, filtrer sur ce critère) | Alimentation |
| Connecteur batterie | JST-PH 2 points, déjà présent côté PCB (BT1, soudé en usine PCBA) | Standard LiPo, polarité gardée |
| Module charge + protection | TP4056 **ou TP4057** (version améliorée, protection inversion de polarité en plus) + DW01A/FS8205A, **variante USB-C** — 🔌 connecteur pré-câblé à privilégier si disponible, sinon exception acceptée (module vendu en carte nue avec pastilles à souder, cas fréquent) | Charge + coupure basse tension automatique (~2,4-3,0V) + protection surcharge/court-circuit |
| Boost 5V | Module boost LiPo→5V (ex. base MT3608) — même remarque que ci-dessus, souvent vendu en carte nue | Tension stable 5V quelle que soit la charge de la batterie |

⚠️ **Le module charge (TP4056/TP4057) et le boost 5V sont deux fonctions distinctes** — certaines cartes combinées ("3 en 1") intègrent les deux sur le même petit PCB, d'autres non. **Vérifié pour le TP4057 en particulier : c'est une puce de charge pure, sans fonction boost.** Si ton module ne fait que charge+protection, il faut un second module boost séparé. Câblage dans ce cas :

```
Batterie (+/-) ──┬──▶ Module TP4057 (bornes BAT) — charge/protection, en parallèle
                  └──▶ Entrée du module boost — aussi en parallèle
Sortie du module boost (5V) ──▶ J2 broches 3/4 sur le PCB
```

Ça ne change rien au PCB (J2 reste 4 broches : BAT+, BAT-, 5V+, 5V-) — juste la façon dont les modules externes se câblent entre eux avant de rejoindre J2.
| Interrupteur | Glissière ou bouton-poussoir à verrouillage, sur la ligne 5V après le boost — 🔌 connecteur pré-câblé obligatoire à l'achat (fils avec Dupont/JST déjà sertis, pas de cosses nues) | Éteindre complètement entre deux events — sans lui l'autonomie 4-6h ne veut plus rien dire si le boîtier reste allumé par oubli |
| Indicateur niveau batterie | Module "1S lithium battery capacity indicator", 4 LED (25/50/75/100%) — 🔌 connecteur pré-câblé obligatoire à l'achat | Branché directement en parallèle sur la batterie (2 fils B+/B-, ~5mA, toujours actif, pas de bouton) — repère `BATLED` sur le PCB |

---

## Carte 1 — Nano + nRF24 (équipe, version principale)

### BOM

| Réf. | Composant | Note |
|---|---|---|
| U1 | Arduino Nano (ou compatible CH340) | Monté en carrier via headers femelles — pas besoin de graver un bootloader séparément |
| U2 | Module nRF24L01+ | **VCC en 3,3V uniquement, jamais 5V** |
| C1 | Condensateur 10-100 µF | Entre VCC et GND du nRF24, obligatoire (bruit radio) |
| SW1 | Bouton-poussoir — 🔌 connecteur pré-câblé obligatoire à l'achat | Buzz |
| M1 | Module vibreur (IN/VCC/GND) — 🔌 connecteur pré-câblé obligatoire à l'achat (voir remarque en début de doc) | Optionnel — voir câblage simplifié ci-dessus |
| — | Bloc alimentation | Voir section commune — **capacité batterie recommandée : 500-600 mAh** (consommation Nano+nRF24 plus faible, ~20-25 mA moyen estimé) |

### Brochage (Nano)

| Signal | Broche Nano | Vers |
|---|---|---|
| nRF24 CE | D9 | Module nRF24 |
| nRF24 CSN | D10 | Module nRF24 |
| nRF24 SCK | D13 | Module nRF24 *(partagée avec LED_BUILTIN — sans incidence, le firmware n'allume la LED que hors transaction SPI)* |
| nRF24 MOSI | D11 | Module nRF24 |
| nRF24 MISO | D12 | Module nRF24 |
| nRF24 VCC | 3,3V (broche Nano) | Module nRF24 |
| nRF24 GND | GND | Module nRF24 |
| Bouton | D2 → GND | Pull-up interne activé par le firmware, pas de résistance externe |
| Vibreur — IN | D5 | Module vibreur |
| Vibreur — VCC | 5V | Sortie du boost |
| Vibreur — GND | GND | — |
| Alimentation | 5V / GND | Sortie du boost |

---

## Carte 2 — ESP32 (secours équipe, ESP-NOW)

### BOM

| Réf. | Composant | Note |
|---|---|---|
| U1 | ESP32 Dev Module | Pas de module radio externe (Wi-Fi/ESP-NOW intégré à la puce) — carte envisagée : ESP32-DevKitC-32, USB-C, **CH340C** (pas encore commandée). Pilote **CH340**, différent du FT232 de la carte hub régie — ne pas confondre au moment d'installer les pilotes. |
| SW1 | Bouton-poussoir — 🔌 connecteur pré-câblé obligatoire à l'achat | Buzz |
| M1 | Module vibreur (IN/VCC/GND) — 🔌 connecteur pré-câblé obligatoire à l'achat (voir remarque en début de doc) | Optionnel — voir câblage simplifié ci-dessus |
| — | Bloc alimentation | Voir section commune — **capacité batterie recommandée : 1000-1200 mAh** (Wi-Fi nettement plus gourmand, ~60-120 mA moyen estimé, ~2x la carte Nano pour la même autonomie) |

### Brochage (ESP32)

| Signal | Broche ESP32 | Vers |
|---|---|---|
| Bouton | GPIO4 → GND | Pull-up interne activé par le firmware |
| LED (feedback + confirmation ESP-NOW) | GPIO2 | LED embarquée sur la plupart des cartes ESP32 Dev Module |
| Vibreur — IN | GPIO13 | Module vibreur |
| Vibreur — VCC | 5V | Sortie du boost |
| Vibreur — GND | GND | — |
| Alimentation | 5V / GND (broche VIN ou 5V selon la carte) | Sortie du boost |

**Rappel important** : `ESPNOW_WIFI_CHANNEL` (canal 6 par défaut) dans `esp32_buzzer_equipe.ino` doit rester identique à celui du hub (`esp32/esp32_bridge_server.ino`) — sans lien avec le PCB, mais à ne pas oublier au premier flash de chaque carte.

---

## Assemblage : connecteurs, pas de soudure directe

- **Nano, nRF24, et le module ESP32** se montent sur des **connecteurs/headers femelles** soudés sur le PCB — pas soudés directement. Facilite le remplacement en cas de panne d'un module.
- **Condensateurs, résistances, et tous les headers femelles/mâles/JST** : assemblage machine (PCBA) chez le fabricant — rien à souder côté carte pour le client.
- **Batterie et tous les modules externes** (vibreur, bouton, interrupteur, charge/boost, indicateur niveau) : câblage par connecteur à l'achat, **pas de soudure** — voir la règle d'achat en tout début de document. Les cartes étant livrées directement au client (pas de passage par Samuel), chaque module doit arriver déjà équipé de son connecteur, sinon le client se retrouve avec un fer à souder à sortir malgré tout le travail fait sur le PCB.

## Ce que ça implique pour le boîtier 3D

Boîtier en **deux étages démontables indépendamment** (voir `hardware/boitier_buzzer_equipe.scad`, rendu et vérifié avec OpenSCAD) :
- **Étage du haut** : PCB + connecteurs + modules, fermé par un couvercle avec le trou du bouton BUZZ. C'est là que sont câblés les headers.
- **Étage du bas** : compartiment batterie séparé, avec sa propre trappe — on peut changer/recharger la batterie sans démonter l'électronique du dessus.
- Une étagère interne sépare les deux, avec une fente de passage pour les fils d'alimentation.
- **Carte ESP32** : batterie ~2x plus grosse (1000-1200 mAh vs 500-600 mAh) → empreinte au sol différente entre les deux variantes (52×28mm de carte ESP32 confirmés par la fiche produit, contre la Nano+nRF24 plus compacte).
- Accès externe prévu au port USB-C (charge, sur l'étage batterie) et à l'interrupteur (sur l'étage PCB), sans avoir à ouvrir les couvercles.
- **Module charge+protection+boost 3-en-1** : loge **dans l'étage batterie**, à côté de la cellule (câblage BAT+/BAT- en parallèle sur la batterie, sortie 5V/GND qui remonte par la fente de passage de câbles jusqu'à J2 sur le PCB). L'étage batterie est maintenant dimensionné pour la batterie **et** ce module côte à côte (avant, il n'y avait de la place que pour la batterie seule) — dimensions du module estimées génériquement (26×18×6mm), **à remesurer sur le module réellement reçu** et ajuster `module_charge_l/p/h` dans le `.scad` si besoin.

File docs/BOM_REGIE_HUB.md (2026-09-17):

# BOM & brochage — Adaptateur Régie/Hub (Mega + ESP32 + nRF24)

Référence pour le schéma KiCad `hardware/kicad_regie_hub/regie_hub_mega_esp32.kicad_sch`. Carte **adaptateur**, pas un shield Mega complet — le shield DMX (`quizkicad/mega`, projet séparé) s'empile déjà directement sur la Mega.

## Alimentation

**Pas de batterie sur cette carte.** Le système est alimenté secteur : on branche la Mega (son régulateur onboard convertit l'alimentation secteur en 5V propre), et cette carte adaptateur — ESP32, nRF24, tout le reste — tire son 5V directement de la Mega via le connecteur `J_MEGA`.

## BOM

| Réf. | Composant | Note |
|---|---|---|
| J_MEGA | Connecteur 6 broches (fils vers la Mega) | TX2, RX2, TX3, RX3, 5V, GND — voir tableau ci-dessous |
| U_ESP32 | ESP32 DevKit V1 (module sur connecteur femelle, pas soudé) | Carte confirmée : FT232, 30 broches, micro-USB |
| J_NRF | Module nRF24L01+ (sur connecteur femelle) | **VCC en 3,3V uniquement, jamais 5V** |
| U_REG | Module régulateur 3,3V (ex. AMS1117-3.3) | Dédié au nRF24 — voir raisonnement dans le README du dossier KiCad |
| R1, R3 | Résistance 1 kΩ | Diviseurs de tension (série) |
| R2, R4 | Résistance 2 kΩ | Diviseurs de tension (vers GND) |
| C1, C2 | Condensateur ~10 µF | Découplage entrée/sortie du régulateur |
| C3 | Condensateur 10-100 µF | Découplage nRF24 (obligatoire, cf. `cl.md` section 3.3) |

## Brochage

| Signal | Vers | Note |
|---|---|---|
| J_MEGA.1 (TX2, 5V) | R1 (entrée diviseur) | Lien Jeu, 19200 bauds |
| R1/R2 (nœud diviseur, 3,3V) | U_ESP32 GPIO26 (RX1) | |
| U_ESP32 GPIO25 (TX1) | J_MEGA.2 (RX2) | Direct, pas de diviseur (3,3V lu HIGH par la Mega) |
| J_MEGA.3 (TX3, 5V) | R3 (entrée diviseur) | Lien Config EEPROM, 9600 bauds |
| R3/R4 (nœud diviseur, 3,3V) | U_ESP32 GPIO16 (RX2) | |
| U_ESP32 GPIO17 (TX2) | J_MEGA.4 (RX3) | Direct |
| U_ESP32 GPIO4/5/18/19/23 | J_NRF CE/CSN/SCK/MISO/MOSI | SPI matériel (VSPI) |
| U_REG VOUT (3,3V dédié) | J_NRF VCC | Pas le 3V3 onboard de l'ESP32 — voir README |
| U_ESP32 GPIO2 | — | LED embarquée, interne au module, rien à router ici |

## À commander (spécifications, pas de lien direct — voir explication dans la conversation)

- **ESP32 DevKit V1** : déjà commandé (FT232, 30 broches, micro-USB) pour cette carte.
- **Module nRF24L01+** : version standard, alimentation 3,3V.
- **Module régulateur AMS1117-3.3** : cherche `AMS1117 3.3V module régulateur LDO`.

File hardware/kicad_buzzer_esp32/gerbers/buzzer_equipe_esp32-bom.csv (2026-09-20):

Designator | Comment | Footprint
BATLED | Indicateur niveau batterie (4 LED) - CMS - 1=B+ 2=B- | Connector_PinSocket_2.54mm:PinSocket_1x02_P2.54mm_Vertical_SMD_Pin1Left
BT1 | Batterie LiPo 1S 1000-1200mAh - connecteur JST-PH (1=+ 2=-) | Connector_JST:JST_PH_B2B-PH-K_1x02_P2.00mm_Vertical
J2 | Module charge TP4056+protect+boost USB-C - CMS | Connector_PinSocket_2.54mm:PinSocket_1x04_P2.54mm_Vertical_SMD_Pin1Left
J3 | Module vibreur IN/VCC/GND - CMS | Connector_PinSocket_2.54mm:PinSocket_1x03_P2.54mm_Vertical_SMD_Pin1Left
SW1 | Bouton BUZZ (fils volants) - CMS | Connector_PinSocket_2.54mm:PinSocket_1x02_P2.54mm_Vertical_SMD_Pin1Left
SW2 | Interrupteur marche/arret (fils volants) - CMS | Connector_PinSocket_2.54mm:PinSocket_1x02_P2.54mm_Vertical_SMD_Pin1Left
U1L | ESP32 colonne gauche (broches 1-19) - VERIFIER sur le module recu | Connector_PinSocket_2.54mm:PinSocket_1x19_P2.54mm_Vertical
U1R | ESP32 colonne droite (broches 20-38) - VERIFIER sur le module recu | Connector_PinSocket_2.54mm:PinSocket_1x19_P2.54mm_Vertical

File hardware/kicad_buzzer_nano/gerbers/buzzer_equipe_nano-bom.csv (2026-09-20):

Designator | Comment | Footprint
A1L | Nano colonne gauche (broches 1-15) | Connector_PinSocket_2.54mm:PinSocket_1x15_P2.54mm_Vertical
A1R | Nano colonne droite (broches 16-30) | Connector_PinSocket_2.54mm:PinSocket_1x15_P2.54mm_Vertical
BATLED | Indicateur niveau batterie (4 LED) - CMS - 1=B+ 2=B- | Connector_PinSocket_2.54mm:PinSocket_1x02_P2.54mm_Vertical_SMD_Pin1Left
BT1 | Batterie LiPo 1S 500-600mAh - connecteur JST-PH (1=+ 2=-) | Connector_JST:JST_PH_B2B-PH-K_1x02_P2.00mm_Vertical
C1 | 10-100uF decouplage nRF24 (obligatoire, au plus pres) - CMS | Capacitor_SMD:C_0805_2012Metric
J1 | nRF24L01+PA+LNA (broches MALES, le module a des ports femelles) - VERIFIER le brochage sur le module recu | Connector_PinHeader_2.54mm:PinHeader_2x04_P2.54mm_Vertical
J2 | Module charge TP4056+protect+boost USB-C - CMS | Connector_PinSocket_2.54mm:PinSocket_1x04_P2.54mm_Vertical_SMD_Pin1Left
J3 | Module vibreur IN/VCC/GND - CMS | Connector_PinSocket_2.54mm:PinSocket_1x03_P2.54mm_Vertical_SMD_Pin1Left
SW1 | Bouton BUZZ (fils volants) - CMS | Connector_PinSocket_2.54mm:PinSocket_1x02_P2.54mm_Vertical_SMD_Pin1Left
SW2 | Interrupteur marche/arret (fils volants) - CMS | Connector_PinSocket_2.54mm:PinSocket_1x02_P2.54mm_Vertical_SMD_Pin1Left

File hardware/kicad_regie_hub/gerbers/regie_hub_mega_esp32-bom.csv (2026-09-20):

Designator | Comment | Footprint
C1 | ~10uF decouplage entree regulateur - CMS | Capacitor_SMD:C_0805_2012Metric
C2 | ~10uF decouplage sortie regulateur - CMS | Capacitor_SMD:C_0805_2012Metric
C3 | 10-100uF decouplage nRF24 (obligatoire, au plus pres) - CMS | Capacitor_SMD:C_0805_2012Metric
J_MEGA | Vers Mega: TX2 RX2 TX3 RX3 5V GND | Connector_PinSocket_2.54mm:PinSocket_1x06_P2.54mm_Vertical
J_NRF | nRF24L01+PA+LNA (broches MALES, le module a des ports femelles) - VERIFIER le brochage sur le module recu | Connector_PinHeader_2.54mm:PinHeader_2x04_P2.54mm_Vertical
R1 | 1k (diviseur TX2, serie) - CMS | Resistor_SMD:R_0805_2012Metric
R2 | 2k (diviseur TX2, vers GND) - CMS | Resistor_SMD:R_0805_2012Metric
R3 | 1k (diviseur TX3, serie) - CMS | Resistor_SMD:R_0805_2012Metric
R4 | 2k (diviseur TX3, vers GND) - CMS | Resistor_SMD:R_0805_2012Metric
U_ESP32L | ESP32 DevKit V1 colonne gauche (broches 1-15) | Connector_PinSocket_2.54mm:PinSocket_1x15_P2.54mm_Vertical
U_ESP32R | ESP32 DevKit V1 colonne droite (broches 16-30) | Connector_PinSocket_2.54mm:PinSocket_1x15_P2.54mm_Vertical
U_REG | Regulateur 3.3V dedie (ex AMS1117-3.3) | Connector_PinSocket_2.54mm:PinSocket_1x03_P2.54mm_Vertical

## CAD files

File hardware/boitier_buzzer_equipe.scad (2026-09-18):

// ==========================================================================
// BOÎTIER BUZZER ÉQUIPE — paramétrique, 2 variantes (Nano+nRF24 / ESP32)
// Architecture 2 étages démontables : étage PCB (modules sur connecteurs
// femelles) en haut avec le bouton, étage batterie en dessous avec sa
// propre trappe — accès à la batterie sans démonter l'électronique.
// ==========================================================================
// Basé sur docs/BOM_BUZZER_EQUIPE.md. Dimensions ESP32 (51,45 x 23,37mm,
// pas 2,54mm, entraxe rangées 22,86mm) vérifiées par recherche web pour un
// DOIT ESP32 DevKit V1 30 broches typique -- À REMESURER sur la carte
// réellement reçue (les clones varient). Dimensions Nano/nRF24/batterie
// toujours approximatives (voir BOM), à ajuster aussi.
//
// Modules montés sur connecteurs femelles (pas soudés directement) : la
// hauteur "hauteur_headers" ci-dessous doit couvrir header femelle +
// épaisseur du module + ses propres composants en hauteur.
//
// Je n'ai pas d'accès root dans cet environnement pour garder OpenSCAD
// installé en permanence : ce fichier a été rendu et vérifié (géométrie
// valide, "Simple: yes") au moment de l'écrire, mais RELISEZ-le et
// ouvrez-le vous-même dans OpenSCAD avant impression -- ne faites pas
// confiance au fichier les yeux fermés.
//
// Utilisation :
//   1. Ouvrez ce fichier dans OpenSCAD.
//   2. Choisissez la variante avec VARIANTE ci-dessous ("nano" ou "esp32").
//   3. F5 pour prévisualiser, F6 pour le rendu final, exportez en .stl.
// ==========================================================================

// ---- CHOIX DE LA VARIANTE ----
VARIANTE = "nano"; // "nano" ou "esp32"

// ---- PARAMÈTRES GÉNÉRAUX (communs aux deux variantes) ----
epaisseur_paroi  = 2.0;   // épaisseur des parois imprimées
jeu              = 0.5;   // jeu (clearance) autour des composants, par côté
hauteur_headers  = 14;    // au-dessus du plancher PCB : header femelle + module + ses composants
hauteur_shelf    = 1.6;   // épaisseur de l'étagère qui sépare étage PCB / étage batterie

// Empreinte de l'étage PCB (modules + connecteurs, côte à côte) -- voir
// note de dimensions ESP32 ci-dessus pour la variante "esp32"
pcb_largeur_nano   = 38;  // Nano (~18mm large) + nRF24 (~15mm) côte à côte + marge
pcb_longueur_nano  = 48;  // le plus long des deux modules (Nano ~43mm) + marge
// ESP32-DevKitC-32 (CH340C, USB-C) : dimensions CONFIRMEES par la fiche
// produit du modele envisage cote equipe -- 52 x 28mm, ~9.5g. Marge de
// degagement ajoutee pour le connecteur/les pattes de header.
pcb_largeur_esp32  = 34;  // 28mm de large + degagement
pcb_longueur_esp32 = 58;  // 52mm de long + marge

// Batterie LiPo (approximatif — À REMESURER sur la cellule réellement achetée)
batterie_nano_l   = 30;   // 500-600 mAh, typique
batterie_nano_p   = 25;
batterie_nano_h   = 7;
batterie_esp32_l  = 50;   // 1000-1200 mAh, typique — bien plus grande
batterie_esp32_p  = 34;
batterie_esp32_h  = 7;

// Module charge+protection+boost 3-en-1 ("Type-C USB 5V Step-Up Booster
// Lithium Battery Charging and Protection Module for Power Bank", ex.
// réf. 134N3P) — loge DANS L'ÉTAGE BATTERIE, à côté de la cellule (câblage
// BAT+/BAT- en parallèle sur la batterie, sortie 5V/GND remonte par la
// fente de passage de câbles jusqu'à J2 sur le PCB). Placé côte à côte
// avec la batterie le long de la largeur -- dimensions estimées
// génériques pour ce type de module, À REMESURER sur le module réellement
// reçu (elles varient pas mal d'un vendeur à l'autre).
module_charge_l = 26;   // longueur (mm)
module_charge_p = 18;   // largeur (mm)
module_charge_h = 6;    // épaisseur, composants compris (mm)

// Bouton "BUZZ" — type arcade, gros et satisfaisant à presser (pas un petit
// bouton tactile 6mm) : diamètre de perçage à ajuster selon le bouton choisi
bouton_diametre  = 24;

// Port USB-C du module de charge (cutout sur l'étage batterie)
usb_c_largeur    = 9.5;
usb_c_hauteur    = 3.5;

// Interrupteur (glissière) — cutout sur l'étage PCB (facile d'accès en haut)
interrupteur_largeur = 12;
interrupteur_hauteur = 6;

// Fente de passage de fils entre étage batterie et étage PCB (alimentation
// + cables du module de charge)
fente_cables_largeur = 10;
fente_cables_hauteur = 3;

// Vis (auto-taraudeuses dans bossages imprimés) -- 3 jeux : couvercle sup.
// -> corps, et corps -> trappe batterie
vis_diametre_ame = 2.4;   // âme pour vis M3 autotaraudeuse
bossage_diametre = 7;
marge_coin       = 6;     // distance des bossages par rapport aux coins

// ---- DIMENSIONS DÉRIVÉES SELON LA VARIANTE ----
pcb_largeur  = (VARIANTE == "esp32") ? pcb_largeur_esp32  : pcb_largeur_nano;
pcb_longueur = (VARIANTE == "esp32") ? pcb_longueur_esp32 : pcb_longueur_nano;
bat_l        = (VARIANTE == "esp32") ? batterie_esp32_l   : batterie_nano_l;
bat_p        = (VARIANTE == "esp32") ? batterie_esp32_p   : batterie_nano_p;
bat_h        = (VARIANTE == "esp32") ? batterie_esp32_h   : batterie_nano_h;

// Empreinte de l'étage batterie = batterie + module charge côte à côte
// (le long de la largeur), pas juste la batterie seule -- sinon le module
// ne rentre pas à côté d'elle dans la trappe du bas.
etage_bat_largeur  = bat_p + module_charge_p + jeu;
etage_bat_longueur = max(bat_l, module_charge_l);
etage_bat_hauteur  = max(bat_h, module_charge_h);

// Étages empilés (pas côte à côte) -> l'empreinte extérieure commune est
// la plus grande des deux compartiments, dans chaque dimension.
interieur_largeur  = max(pcb_largeur, etage_bat_largeur) + 2*jeu;
interieur_longueur = max(pcb_longueur, etage_bat_longueur) + 2*jeu;
exterieur_largeur  = interieur_largeur  + 2*epaisseur_paroi;
exterieur_longueur = interieur_longueur + 2*epaisseur_paroi;

hauteur_etage_pcb      = hauteur_headers;
hauteur_etage_batterie = etage_bat_hauteur + 2*jeu + 2; // +2mm de marge de manoeuvre

$fn = 48; // résolution des cercles/cylindres

// ---- BOÎTE ARRONDIE (helper) ----
module boite_arrondie(l, p, h, rayon) {
    hull() {
        for (x = [rayon, l - rayon])
            for (y = [rayon, p - rayon])
                translate([x, y, 0])
                    cylinder(h = h, r = rayon);
    }
}

// ---- POSITIONS DES BOSSAGES DE VIS (4 coins) ----
function pos_bossages() = [
    [marge_coin, marge_coin],
    [exterieur_largeur - marge_coin, marge_coin],
    [marge_coin, exterieur_longueur - marge_coin],
    [exterieur_largeur - marge_coin, exterieur_longueur - marge_coin]
];

// ==========================================================================
// CORPS PRINCIPAL : étage PCB (haut, fermé) + étagère + étage batterie
// (bas, OUVERT -- ferme par la trappe séparée). Un seul corps imprimé,
// mais deux volumes internes accessibles indépendamment : couvercle
// supérieur pour le PCB, trappe du dessous pour la batterie.
// ==========================================================================
module corps_principal() {
    hauteur_totale = hauteur_etage_pcb + hauteur_shelf + hauteur_etage_batterie;

    difference() {
        union() {
            boite_arrondie(exterieur_largeur, exterieur_longueur, hauteur_totale, 4);

            // Bossages de vis (pleins sur toute la hauteur, perces plus bas)
            for (pos = pos_bossages())
                translate([pos[0], pos[1], 0])
                    cylinder(h = hauteur_totale, d = bossage_diametre);
        }

        // Cavité étage batterie (en bas, ouverte vers le dessous)
        translate([epaisseur_paroi, epaisseur_paroi, -1])
            cube([interieur_largeur, interieur_longueur, hauteur_etage_batterie + 1]);

        // Cavité étage PCB (au-dessus de l'étagère, ouverte vers le dessus
        // -- fermée par le couvercle supérieur)
        translate([epaisseur_paroi, epaisseur_paroi, hauteur_etage_batterie + hauteur_shelf])
            cube([interieur_largeur, interieur_longueur, hauteur_etage_pcb + 1]);

        // Fente de passage des câbles à travers l'étagère
        translate([exterieur_largeur/2 - fente_cables_largeur/2,
                   epaisseur_paroi - 0.5,
                   hauteur_etage_batterie])
            cube([fente_cables_largeur, fente_cables_hauteur, hauteur_shelf + 1]);

        // Avant-trous vis (traversant tout le corps, tête côté couvercle sup.,
        // écrou/auto-taraudage côté trappe -- simplifié en trou simple ici)
        for (pos = pos_bossages())
            translate([pos[0], pos[1], -1])
                cylinder(h = hauteur_totale + 2, d = vis_diametre_ame);

        // Découpe USB-C sur l'étage batterie (accès au port de charge)
        translate([exterieur_largeur/2 - usb_c_largeur/2,
                   -1,
                   hauteur_etage_batterie/2 - usb_c_hauteur/2 + epaisseur_paroi/2])
            cube([usb_c_largeur, epaisseur_paroi + 2, usb_c_hauteur]);
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

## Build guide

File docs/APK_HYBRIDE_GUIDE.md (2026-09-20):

# Guide de Génération des Apps Hybrides & Câblage ESP32

Ce guide vous explique comment transformer les interfaces web (Animateur+Public, Régie/Config) en **applications Android (.apk)**, **desktop (Windows/macOS)**, ce qu'il en est pour iOS, et comment câbler et téléverser le firmware dans l'**ESP32**.

---

## 📱 Option 1 : Installation Instantanée PWA (Recommandée — 0 Compilation)

Grâce au fichier [`manifest.json`](file:///home/samuel/Downloads/dev%20projet/dmxproject/web/manifest.json) et aux métadonnées mobiles configurées :

1. Connectez votre smartphone au réseau Wi-Fi de l'ESP32 : **`QuizDMX-Pro`** (Mot de passe : `quizdmx123`).
2. Ouvrez Google Chrome sur votre téléphone et allez à l'adresse : **`http://192.168.4.1/animateur.html`** (ou `http://quizdmx.local/animateur.html`).
3. Appuyez sur les **3 petits points verticaux** en haut à droite du navigateur.
4. Sélectionnez **« Ajouter à l'écran d'accueil »** ou **« Installer l'application »**.
5. **Résultat :** L'application s'installe avec son icône dédiée, se lance en plein écran sans barre d'adresse et vibre à chaque buzz comme une application native 100% Android !

*Ça marche exactement pareil pour `config.html` (Régie) ou `public.html` — changez juste l'adresse à l'étape 2.*

---

## 🛠️ Option 2 : Compilation d'un véritable fichier `.apk` avec Capacitor

Si vous devez distribuer un fichier installable par clé USB ou WhatsApp, il y a **deux applications séparées** (pas une seule qui bundle tout) :

| App | Dossier | Pages incluses | Pourquoi séparée |
|---|---|---|---|
| **Quiz Animateur** | [`hybrid-app-animateur/`](../hybrid-app-animateur) | `animateur.html` + `public.html` (mini-portail au démarrage) | Usage courant, à distribuer largement |
| **Quiz Régie** | [`hybrid-app-config/`](../hybrid-app-config) | `config.html` uniquement | Pilote le DMX en direct — protégée par son propre mot de passe (voir [GUIDE_CLIENT.md](GUIDE_CLIENT.md)), à ne pas distribuer aussi largement que l'app Animateur |

### Option 2a — Le plus simple : récupérer l'APK déjà compilé (GitHub Actions)

Chaque push sur `main` déclenche automatiquement la compilation des deux APK (workflow **Build Hybrid Apps (Android APK)**) :

1. Allez sur l'onglet **Actions** du dépôt GitHub.
2. Ouvrez le dernier run réussi de **Build Hybrid Apps (Android APK)**.
3. Dans **Artifacts**, téléchargez `hybrid-app-animateur-debug-apk` ou `hybrid-app-config-debug-apk`.
4. Transférez le `.apk` sur le téléphone Android (USB, WhatsApp, e-mail…) et installez-le (autoriser « sources inconnues » si demandé).

C'est un **APK de debug non signé** — parfait pour un usage interne/événementiel, mais pas pour une publication sur le Play Store (ça demanderait une signature de release, hors périmètre ici).

### Option 2b — Compiler soi-même en local

**Prérequis** : [Node.js](https://nodejs.org) (v18+), [Android Studio](https://developer.android.com/studio) avec le SDK Android.

Pour **chaque** app (remplacez `hybrid-app-animateur` par `hybrid-app-config` pour l'autre) :

```bash
cd hybrid-app-animateur
npm install
npm run init:android   # une seule fois : scaffolding du projet Android
npm run sync           # copie les fichiers de web/ dans www/, puis cap copy + cap sync
npm run build:apk      # ./gradlew assembleDebug
```

L'APK généré se trouve dans `hybrid-app-animateur/android/app/build/outputs/apk/debug/app-debug.apk`.

*Pour ouvrir dans Android Studio (déboguer, changer l'icône…) à la place de la ligne de commande :* `npm run open:android`.

> [!IMPORTANT]
> `capacitor.config.json` inclut déjà `"cleartext": true`. C'est **obligatoire** sur Android moderne pour autoriser la connexion au point d'accès Wi-Fi local non-chiffré `http://192.168.4.1` et au WebSocket `ws://192.168.4.1/ws`.

### 🍎 Et pour iOS ?

Un projet Capacitor iOS existe aussi (`npm run init:ios`, `npm run sync`, `npm run open:ios`) et une CI (**Build Hybrid Apps (iOS, verification simulateur)**) vérifie automatiquement qu'il compile — mais **uniquement pour le simulateur, sans signature**. Produire une vraie app installable sur un iPhone demande obligatoirement :

- Un **compte Apple Developer** (payant, ~99$/an),
- Un **Mac avec Xcode** pour l'étape finale d'archivage/signature,
- Des certificats et profils de provisionnement configurés dans le compte Apple.

Rien de tout ça n'est automatisable sans que vous (ou le client) fournissiez ce compte — c'est une contrainte d'Apple, pas une limite de ce projet. Si vous avez un compte Apple Developer, ouvrez `ios/App.xcworkspace` dans Xcode après `npm run sync` et suivez le flux Apple habituel (Signing & Capabilities → Archive → distribuer).

---

## 🖥️ Option 3 : Application desktop (Windows / macOS)

Utile pour un client qui préfère une icône dédiée sur le Bureau plutôt que d'ouvrir un navigateur et taper `192.168.4.1` — même principe que les apps mobiles, via [`@capawesome/capacitor-electron`](https://capawesome.io/docs/sdks/capacitor/electron/) (la plateforme Electron **maintenue** pour Capacitor 6 ; l'ancienne `@capacitor-community/electron` est abandonnée et connue pour des soucis de compatibilité avec Capacitor 6 — ne pas l'utiliser).

### Option 3a — Récupérer l'installeur déjà compilé (GitHub Actions)

Chaque push sur `main` compile automatiquement les deux apps pour **Windows et macOS** (workflow **Build Hybrid Apps (Desktop Windows + macOS)**) :

1. Onglet **Actions** du dépôt GitHub → dernier run réussi de ce workflow.
2. Dans **Artifacts**, téléchargez `hybrid-app-animateur-desktop-windows-latest`, `hybrid-app-animateur-desktop-macos-latest`, ou l'équivalent `hybrid-app-config-desktop-*`.
3. Windows : lancez le `.exe`. macOS : ouvrez le `.dmg` et glissez l'app dans Applications (macOS peut demander d'autoriser l'app dans Réglages Système → Confidentialité et sécurité, l'app n'étant pas signée par un compte Apple Developer — voir note ci-dessous).

### Option 3b — Compiler soi-même en local

**Prérequis** : [Node.js](https://nodejs.org) (v18+).

```bash
cd hybrid-app-animateur
npm install
npm run init:electron    # une seule fois : ajoute la plateforme Electron
npm run sync:electron    # copie web/ dans www/, puis cap sync vers electron/
npm run build:electron   # compile l'installeur (electron-builder)
```

L'installeur se trouve dans `hybrid-app-animateur/electron/dist/` (`.exe` sous Windows, `.dmg`/`.zip` sous macOS — vous ne pouvez compiler que pour l'OS sur lequel vous lancez la commande, comme pour n'importe quel outil Electron).

> [!NOTE]
> Comme les APK, ce sont des builds **non signés** (aucun certificat de signature de code Windows/Apple configuré). Windows peut afficher un avertissement SmartScreen, macOS peut bloquer l'app au premier lancement (clic droit → Ouvrir, ou l'autoriser dans Réglages Système). Suffisant pour un usage interne/événementiel ; une distribution plus large demanderait un certificat de signature (payant, hors périmètre ici).

---

## 🔌 Câblage Matériel Complet : ESP32 ↔ nRF24L01+ ↔ Arduino Mega 2560

### 1. nRF24L01+ vers ESP32 (Bus SPI VSPI)
| Broche nRF24L01 | Broche ESP32 | Remarques critiques |
| :--- | :--- | :--- |
| **VCC** | **3.3V** | ⚠️ **JAMAIS LE 5V !** Risque de destruction immédiate de la puce RF. |
| **GND** | **GND** | Masse commune. |
| **CE** | **GPIO 4** | Activation émetteur/récepteur. |
| **CSN** | **GPIO 5** | Chip Select SPI. |
| **SCK** | **GPIO 18** | Horloge matérielle SPI. |
| **MISO** | **GPIO 19** | Données entrantes SPI. |
| **MOSI** | **GPIO 23** | Données sortantes SPI. |

> [!TIP]
> **Condensateur de découplage nRF24** : Soudez un condensateur électrolytique de **10 µF à 100 µF** directement entre les broches VCC et GND du module nRF24. Cela élimine 99% des bruits de transmission et évite les blocages radio.

---

### 2. ESP32 vers Arduino Mega 2560
| Fonction | Sortie ESP32 | Entrée Mega 2560 | Adaptation de tension |
| :--- | :--- | :--- | :--- |
| **Masse** | **GND** | **GND** | **Liaison directe obligatoire** |
| **Jeu (Buzz / Commandes)** | **GPIO 25 (TX1)** | **Pin 17 (RX2)** | Direct (Le Mega 5V accepte le 3.3V HIGH) |
| **Jeu (Retours Mega)** | **GPIO 26 (RX1)** | **Pin 16 (TX2)** | **Pont diviseur 1kΩ / 2kΩ** (5V ➔ 3.3V) |
| **Config EEPROM** | **GPIO 17 (TX2)** | **Pin 19 (RX1)** | Direct |
| **Config (Retours Mega)** | **GPIO 16 (RX2)** | **Pin 18 (TX1)** | **Pont diviseur 1kΩ / 2kΩ** (5V ➔ 3.3V) |

⚠️ **[FIX] Lien Config déplacé de Mega Serial3 (pins 14/15) vers Mega Serial1 (pins 18/19)** — Serial3 était déjà utilisé par le shield DMX (mal aiguillé côté firmware avant correction) et reste maintenant dédié au câble TTL PC (scripts Python) comme secours simultané au WiFi. Serial1 était libre. Voir `megaf.ino` et `esp32/esp32_bridge_server.ino`. (Au passage, l'ancienne version de ce tableau avait aussi RX3/TX3 inversés — 14 est TX3 et 15 est RX3 en réalité, sans conséquence puisque ce lien a changé de port.)

*Schéma du pont diviseur recommandé pour chaque fil 5V Mega TX -> ESP32 RX :*
```text
Mega TX (5V) ───[ 1 kΩ ]───┬───> ESP32 RX (3.3V)
                           │
                       [ 2 kΩ ]
                           │
                          GND
```

---

## 🚀 Téléversement du Firmware et des Fichiers Web sur l'ESP32

### 0. Préparer Arduino IDE (une seule fois, si ce n'est pas déjà fait)

1. Installez **Arduino IDE 2.x** (la version actuelle, [arduino.cc/en/software](https://www.arduino.cc/en/software)).
2. Ajoutez le support des cartes ESP32 :
   - Menu **Fichier > Préférences** (ou **Arduino IDE > Paramètres** sur Mac).
   - Dans **« URL de gestionnaire de cartes supplémentaires »**, collez :
     ```
     https://espressif.github.io/arduino-esp32/package_esp32_index.json
     ```
   - **Outils > Type de carte > Gestionnaire de cartes**, cherchez `esp32` (par Espressif Systems) et installez-le.
   - Redémarrez Arduino IDE.
3. Installez les bibliothèques requises via **Outils > Gérer les bibliothèques** (cherchez chaque nom, installez la version proposée en premier) :
   - `ESPAsyncWebServer`
   - `AsyncTCP`
   - `RF24` (par TMRh20)
   - `ArduinoJson` (v6 ou plus récent)
   - *(`WiFi`, `ESPmDNS`, `LittleFS`, `SPI` sont déjà inclus avec le support ESP32, rien à installer)*
4. Installez l'outil d'envoi LittleFS (nécessaire pour téléverser les fichiers `web/` séparément du code) :
   - Téléchargez le fichier `.vsix` le plus récent depuis [github.com/earlephilhower/arduino-littlefs-upload/releases](https://github.com/earlephilhower/arduino-littlefs-upload/releases).
   - Placez-le dans le dossier `~/.arduinoIDE/plugins/` (le créer s'il n'existe pas ; sous Windows : `C:\Users\<votre-nom>\.arduinoIDE\plugins\`).
   - Redémarrez Arduino IDE.

### 1. Téléverser le code Arduino :
1. Ouvrez [`esp32/esp32_bridge_server.ino`](file:///home/samuel/Downloads/dev%20projet/dmxproject/esp32/esp32_bridge_server.ino) dans l'Arduino IDE.
2. Choisissez le type de carte : **Outils > Type de carte > ESP32 Arduino > ESP32 Dev Module** (ou **NodeMCU-32S**).
3. **Outils > Partition Scheme** : choisissez **« Default 4MB with spiffs (1.2MB APP/1.5MB SPIFFS) »** (ou un schéma offrant au moins 1.5 Mo pour les fichiers web — le dossier `esp32/data/` fait environ 1,3 Mo).
4. Branchez l'ESP32 en USB, sélectionnez le bon port dans **Outils > Port**, puis cliquez sur **Téléverser**.

### 2. Téléverser l'interface Web dans LittleFS :
1. Lancez le script de synchronisation pour copier les dernières modifications de `web/` vers `esp32/data/` :
   ```bash
   ./sync_web_to_esp32.sh
   ```
2. Dans Arduino IDE 2.x : `Ctrl+Maj+P` (ou `⌘+Maj+P` sur Mac), tapez et sélectionnez **« Upload LittleFS to Pico/ESP8266/ESP32 »**.
   *(Fermez le Moniteur Série avant de lancer l'envoi, sinon le port est occupé et l'envoi échoue.)*
3. Démarrez l'ESP32 : il crée automatiquement le Wi-Fi `QuizDMX-Pro` et sert immédiatement les interfaces !

### 🩹 Dépannage courant

| Symptôme | Cause probable | Solution |
| :--- | :--- | :--- |
| Aucun port ne s'affiche dans **Outils > Port** | Pilote USB-série manquant | Installez le pilote correspondant à la puce de votre carte ESP32 (**FTDI VCP** pour la carte ESP32 DevKit V1/FT232 confirmée pour le hub régie ; sinon souvent **CP210x** ou **CH340** selon le fabricant — cherchez le nom exact inscrit sur la puce USB de votre carte + « driver » sur le site du fabricant). |
| Erreur *"Sketch too big"* / dépasse l'espace disponible | Partition Scheme trop petite pour le code | Reprenez l'étape 1.3 : choisissez un schéma avec plus d'espace APP. |
| L'envoi LittleFS échoue ou le port se ferme tout seul | Moniteur Série encore ouvert, ou mauvais port sélectionné | Fermez le Moniteur Série, revérifiez **Outils > Port**. |
| Page de secours au lieu de l'interface | Fichiers `web/` pas encore envoyés en LittleFS | Refaites l'étape 2 ci-dessus (le firmware seul ne suffit pas, il faut aussi l'envoi LittleFS séparé). |

---

## 🔄 Synchroniser le logiciel Python et l'application de configuration

La **Mega** est la référence commune : le logiciel Python (`config_final_30.py`) et l'appli web (`config.html` / APK Régie) y écrivent chacun leur configuration (`SET_...` puis `SAVE_CONFIG`), et peuvent maintenant **la relire** avec le bouton **« Lire depuis la Mega »** (commande `GET_CONFIG`).

- Configuré dans le **logiciel Python** → cliquer **SYNCHRONISER MEGA**, puis dans l'appli : **⬇ Lire depuis la Mega**.
- Configuré dans **l'appli** → **⚡ Synchroniser la Mega**, puis dans le logiciel Python : **LIRE DEPUIS LA MEGA**.
- Sont synchronisés : projecteurs (adresse, canaux, décalages, strobe, mode), nombre d'équipes, couleur de chaque équipe par projecteur, durée de strobe par équipe.
- **Ne sont pas dans la Mega** (donc propres à chaque outil) : noms d'équipes, scores, questions, sons. La lecture les conserve dans l'appli.
- La lecture est **refusée pendant une manche** (après un buzz, tant que rien n'est validé/refusé) pour ne jamais gêner le jeu ; elle est non bloquante et dure moins d'une seconde pour une config normale.
- Le **logiciel score** (`QuizBoardV6`, `interface_30eq.py`) a aussi un bouton **« Lire Mega »** : il lit les couleurs DMX de chaque équipe directement dans la Mega (câble TTL branché), en **lecture seule**, à la place de l'import du fichier JSON « Couleurs DMX... ». Il signale si le nombre d'équipes de la Mega diffère de celui du logiciel.
- Le logiciel Python sauvegarde l'ancienne config PC en `config_quiz_pro.json.bak` avant d'être remplacée.
- Nécessite la Mega **et** l'ESP32 reflashés avec cette version (nouveau `megaf.ino` + `esp32_bridge_server.ino`) et l'upload LittleFS du dossier `data/`.

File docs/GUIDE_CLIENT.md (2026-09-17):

# Guide client — Téléverser le système, Wi-Fi, limites

Ce guide couvre l'ensemble des cartes du système : comment reflasher chacune,
combien d'équipes maximum, et comment se connecter en Wi-Fi le jour J.

---

## 1. Vue d'ensemble des cartes

| Rôle | Fichier `.ino` | Carte | Obligatoire ? |
|---|---|---|---|
| Logique de jeu + DMX | `megaf.ino` | Arduino MEGA 2560 | **Oui, toujours** |
| Hub radio + Wi-Fi + serveur web | `esp32/esp32_bridge_server.ino` | ESP32 DevKit V1, FT232, 30 broches, micro-USB *(commandée)* | Oui (remplace le RF-Nano) |
| *Alternative au hub ESP32* | `rf_nano_bridge.ino` | RF-Nano (Nano + nRF24 intégré) | Seulement si vous n'utilisez pas l'ESP32 |
| Buzzer d'équipe | `buzzer_nano_equipe.ino` | Nano + module nRF24L01 | Un par équipe |
| *Secours équipe (si nRF24 pose problème)* | `esp32_buzzer_equipe.ino` | ESP32 | Optionnel, en remplacement d'un boîtier équipe |
| Télécommande animateur | `nano_animateur_final.ino` | Nano + module nRF24L01 | Oui |
| *Secours animateur* | `esp32_animateur.ino` | ESP32 | Optionnel, en remplacement du boîtier animateur |
| Son (DFPlayer) | `nano_son_final.ino` | Nano + DFPlayer Mini + module nRF24L01 | Selon le mode choisi (voir [MODES.md](../MODES.md)) |

**Vous n'avez normalement besoin que d'UNE version par rôle** (soit la version Nano+nRF24, soit la version ESP32 de secours) — les deux ne sont utiles ensemble que si vous voulez un boîtier de remplacement prêt en cas de souci radio. Voir [MODES.md](../MODES.md#architecture-de-secours--équipesanimateur-en-esp32--esp-now-sans-nrf24) pour le détail de cette architecture de secours.

---

## 2. Pré-requis communs

1. **Arduino IDE 2.x** installé ([arduino.cc/en/software](https://www.arduino.cc/en/software)).
2. **Câble USB** adapté à chaque carte (micro-USB pour la plupart des Nano/ESP32, parfois USB-C selon le modèle).
3. Si une carte n'apparaît pas dans **Outils > Port** : voir le tableau de dépannage en bas de ce guide.
4. **Carte du hub (régie centrale) confirmée** : ESP32 DevKit V1, puce USB-série **FT232**, 30 broches, micro-USB. Si elle n'apparaît pas dans **Outils > Port**, c'est le pilote **FTDI VCP** qu'il faut installer (pas CP210x ni CH340, ce n'est pas la puce de cette carte).

---

## 3. Téléverser chaque carte

### 3.1 Arduino MEGA 2560 — `megaf.ino`

1. Ouvrez `megaf.ino` dans Arduino IDE.
2. **Outils > Type de carte** : `Arduino Mega or Mega 2560`.
3. **Outils > Processeur** : `ATmega2560 (Mega 2560)`.
4. Aucune bibliothèque externe à installer (`DMXSerial` et `EEPROM` sont soit incluses, soit à installer via le Gestionnaire de bibliothèques si le compilateur les réclame).
5. Sélectionnez le port, cliquez sur **Téléverser**.

### 3.2 ESP32 hub — `esp32/esp32_bridge_server.ino`

Procédure complète (support ESP32, bibliothèques, partition, envoi LittleFS des fichiers web) : voir [APK_HYBRIDE_GUIDE.md](APK_HYBRIDE_GUIDE.md#-téléversement-du-firmware-et-des-fichiers-web-sur-lesp32).

### 3.3 RF-Nano — `rf_nano_bridge.ino` (si vous n'utilisez pas l'ESP32 comme hub)

1. **Outils > Type de carte** : `Arduino Nano`.
2. **Outils > Processeur** : `ATmega328P (Old Bootloader)` si le téléversement échoue avec le processeur standard (fréquent sur les clones).
3. Bibliothèques : `RF24` (par TMRh20).
4. **Débranchez le fil de liaison vers la Mega avant de téléverser** (broches D0/D1 partagées avec l'USB, voir cl.md section pièges connus).

### 3.4 Buzzer d'équipe — `buzzer_nano_equipe.ino`

1. **Outils > Type de carte** : `Arduino Nano` (+ `ATmega328P (Old Bootloader)` si besoin).
2. Bibliothèque : `RF24`.
3. **Avant de téléverser, changez le numéro d'équipe** en haut du fichier :
   ```cpp
   int monEquipe = 3; // <- changez ce chiffre pour chaque boîtier (1 à 30)
   ```
4. Téléversez. Répétez pour chaque équipe avec un numéro différent.

### 3.5 Secours équipe ESP32 — `esp32_buzzer_equipe.ino`

1. **Outils > Type de carte** : `ESP32 Dev Module` (voir §2 d'[APK_HYBRIDE_GUIDE.md](APK_HYBRIDE_GUIDE.md) si le support ESP32 n'est pas encore installé).
2. Changez `int monEquipe = 3;` comme pour la version Nano.
3. Vérifiez que `ESPNOW_WIFI_CHANNEL` (canal 6 par défaut) est **identique** à celui du hub ESP32 — sinon le boîtier n'émettra dans le vide.
4. Téléversez.

### 3.6 Télécommande animateur — `nano_animateur_final.ino` (ou `esp32_animateur.ino`)

Même procédure que le buzzer d'équipe (Nano + `RF24`, ou ESP32 + vérification du canal ESP-NOW pour la version de secours). Pas de numéro d'équipe à changer ici.

### 3.7 Nano son — `nano_son_final.ino`

1. **Outils > Type de carte** : `Arduino Nano`.
2. Bibliothèques : `RF24`, `DFRobotDFPlayerMini`, `SoftwareSerial` (incluse).
3. Préparez la carte microSD du DFPlayer **avant** de l'insérer : dossier `mp3/` à la racine avec les fichiers `0001.mp3`, `0101.mp3`, `0102.mp3`… (voir [MODES.md](../MODES.md#correspondance-des-noms-de-fichiers-équipe-1-)).

---

## 4. Nombre maximum d'équipes

**30 équipes**, en dur dans le code — pas un réglage modifiable depuis les interfaces.

Cette limite vient du dimensionnement des tableaux dans **toutes** les cartes à la fois : `settings.couleurs[30][30][3]`, `adressesDMX[30]`, `profils[30]` et `strobeDureeMs[30]` sur la Mega (`megaf.ino`), `MAX_EQUIPES = 30` sur l'ESP32 (`esp32_bridge_server.ino`), et le plafond de 30 déjà imposé par les deux logiciels Python et l'interface web. La Mega tient tout juste dans ses 4 Ko d'EEPROM avec cette taille (≈3,3 Ko utilisés).

Un plafond encore plus dur existe côté nano son (`nano_son_final.ino`) : `teamTrackKnownOk` est un masque de bits sur 32 bits, donc **32 équipes est le maximum physique absolu** sans changer ce type de donnée.

**Pour dépasser 30**, il faudrait recompiler et reflasher toutes les cartes après avoir augmenté ces tailles de tableau partout à la fois, et revérifier que la Mega tient toujours dans ses 4 Ko d'EEPROM — ce n'est pas un simple réglage, c'est une modification du firmware. À éviter sauf besoin réel.

---

## 5. Connexion Wi-Fi (architecture ESP32)

1. Sur votre téléphone/tablette/PC, ouvrez les réglages Wi-Fi et connectez-vous au réseau :
   - **SSID** : `QuizDMX-Pro`
   - **Mot de passe** : `quizdmx123`
2. Ouvrez un navigateur et allez à :
   - `http://192.168.4.1` (adresse fixe, marche toujours)
   - ou `http://quizdmx.local` (plus simple à retenir, nécessite que l'appareil supporte mDNS — marche sur la plupart des téléphones/PC récents)
3. Vous arrivez sur le portail (`index.html`) : choisissez **Animateur**, **Régie/Configuration** ou **Écran Public** selon l'appareil.
4. **Un seul appareil peut faire la régie/config à la fois**, mais plusieurs animateurs/écrans publics peuvent être connectés simultanément (tous synchronisés en temps réel via WebSocket).
5. **La page Régie/Configuration a son propre mot de passe** (`regie2026` par défaut), distinct du mot de passe Wi-Fi — n'importe qui connecté au réseau peut sinon ouvrir cette page et modifier le DMX en direct. Ce mot de passe est vérifié à deux niveaux : l'écran de verrouillage à l'ouverture de la page (`config.js`), et une seconde vérification côté ESP32 avant tout envoi réel vers la Mega (`esp32_bridge_server.ino`) — la seconde est la vraie protection, la première n'est qu'un confort visuel.
   **Pour le changer** : éditez `CONFIG_PASSWORD` dans **les deux fichiers** (`web/config.js` et `esp32/esp32_bridge_server.ino`), avec la **même valeur**, puis relancez `sync_web_to_esp32.sh` et reflashez le hub ESP32 (voir §3.2).

**Changer le SSID/mot de passe** : modifiables dans `esp32/esp32_bridge_server.ino` (`AP_SSID`, `AP_PASS`), à retéléverser ensuite.

---

## 6. Dépannage rapide

| Symptôme | Solution |
|---|---|
| Carte invisible dans **Outils > Port** | Installer le pilote USB-série (CH340, CP210x ou FTDI VCP selon la carte — cherchez le nom de la puce USB inscrite dessus). |
| Nano ne se laisse pas téléverser | Essayez **Processeur > ATmega328P (Old Bootloader)** (fréquent sur les clones). |
| Page de secours au lieu de l'interface web | Les fichiers `web/` n'ont pas encore été envoyés en LittleFS — voir §3.2. |
| Boîtier ESP32 de secours ne buzz jamais | Vérifiez que `ESPNOW_WIFI_CHANNEL` est identique entre ce boîtier et le hub. |
| Deux enceintes jouent en même temps | Voir [MODES.md](../MODES.md) — un seul chemin son actif à la fois (PC ou DFPlayer), pas les deux. |
| "Synchronisation refusée : mot de passe Régie incorrect" | `CONFIG_PASSWORD` ne correspond pas entre `web/config.js` et `esp32/esp32_bridge_server.ino` — remettez la même valeur des deux côtés et reflashez le hub. |

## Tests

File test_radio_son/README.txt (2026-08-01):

Test radio Mega <-> Nano son (commandes 200 / 201 / 202)
=====================================================

0) nano_test_dfplayer_seul  (Nano : DFPlayer + radio, avec mega_test_son_tx)
   - Dossier : nano_test_dfplayer_seul / nano_test_dfplayer_seul.ino
   - Radio nRF24 CE=9 CSN=10 + DFPlayer D5/D4 (meme cablage que nano_son_final.ino).
   - Par defaut (RUN_STARTUP_MP3_SEQUENCE=1) : apres init, joue en local 0001 / 0002 / 0003
     pour verifier la SD, puis ecoute la Mega qui envoie 200 / 201 / 202 (meme pistes).
   - Mettre RUN_STARTUP_MP3_SEQUENCE a 0 dans le .ino pour sauter la sequence locale et
     tester tout de suite avec la Mega seulement.
   - TEST_DFPLAYER_SKIP_INIT=1 : radio + serie sans DFPlayer (debug).
   - Si le moniteur reste sur "Pret" sans RECU : verifier Mega TX allumee, moniteur **9600 baud**,
     cablage nRF24. Le sketch re-appelle startListening() toutes les ~2,5 s et affiche un rappel
     apres **30 s** sans paquet valide (200/201/202).
     Le sketch ne coupe la radio que le temps d'un play/stop DF (dfPlayTrack), pas pendant
     tout le buzz — sinon la Mega peut envoyer 201/202 pendant stopListening et les paquets
     se perdent (FIFO 3 niveaux). Un paquet par tour de loop. Ne pas vider la FIFO RX en fin
     de setup : sinon le premier 200 (BUZZ) est souvent jete avant loop().

1) mega_test_son_tx
   - Ouvrir dans Arduino IDE le dossier mega_test_son_tx / mega_test_son_tx.ino
   - Carte : Arduino Mega 2560
   - Moniteur serie 9600 baud. Cycle ~11,5 s : 200, pause ~2,8 s, 201, pause ~2,8 s, 202.
     La Mega test n'appelle plus startListening() apres chaque envoi (emission seule).
     Le Nano traite un paquet par tour de loop (pas de while sur toute la FIFO d'un coup).
   - L'emission utilise write(..., true) (paquet NO_ACK) car le Nano son est en setAutoAck(false)
     et ne renvoie pas d'ACK : sans cela le moniteur Mega affiche TX FAIL a tort (MAX_RT).

2) nano_test_son_rx
   - Ouvrir nano_test_son_rx / nano_test_son_rx.ino
   - Carte : Arduino Nano
   - Même câblage DFPlayer que nano_son_final.ino (RX=D5, TX=D4)
   - Carte SD : mp3/0001.mp3, 0002.mp3, 0003.mp3, et 0101.mp3 pour buzz équipe 1
   - Moniteur série 9600 baud : lignes des le demarrage (radio avant DFPlayer).
   - Si le moniteur reste vide : DFPlayer::begin() bloque souvent sans module — dans
     nano_test_son_rx.ino mettre TEST_RX_SKIP_DFPLAYER a 1 pour tester radio + serie sans MP3.

Conditions identiques au projet principal :
- Adresse pipe son : "00002" (5 octets + '\0' dans le tableau)
- Canal RF : 108
- Débit : 250 kbps, CRC 16 bits
- Paquet : SonPayload = uint16_t cmd + uint8_t team + uint8_t reserved (4 octets)
- Mega : CE=9, CSN=53  |  Nano : CE=9, CSN=10
- megaf : **double** envoi (~8 ms) pour **201 et 202** seulement ; le **200 (buzz)** part
  **une fois** (eviter que le Nano traite le 2e 200 comme doublon et supprime tout le buzz).
  Les Nanos dedoublonnent seulement 201/202 sur ~160 ms.

nano_test_son_rx inclut déjà le DFPlayer comme nano_son_final.ino (mêmes play 1/2/3 et 100+team).

nano_son_final.ino : radio alignee sur la Mega (setPayloadSize 4 octets, CRC 16, adresses 5).
  Ne pas vider la FIFO en fin de setup pour ne pas perdre le premier paquet son.

Alternative : téléverser nano_son_final.ino à la place du récepteur test — même protocole.

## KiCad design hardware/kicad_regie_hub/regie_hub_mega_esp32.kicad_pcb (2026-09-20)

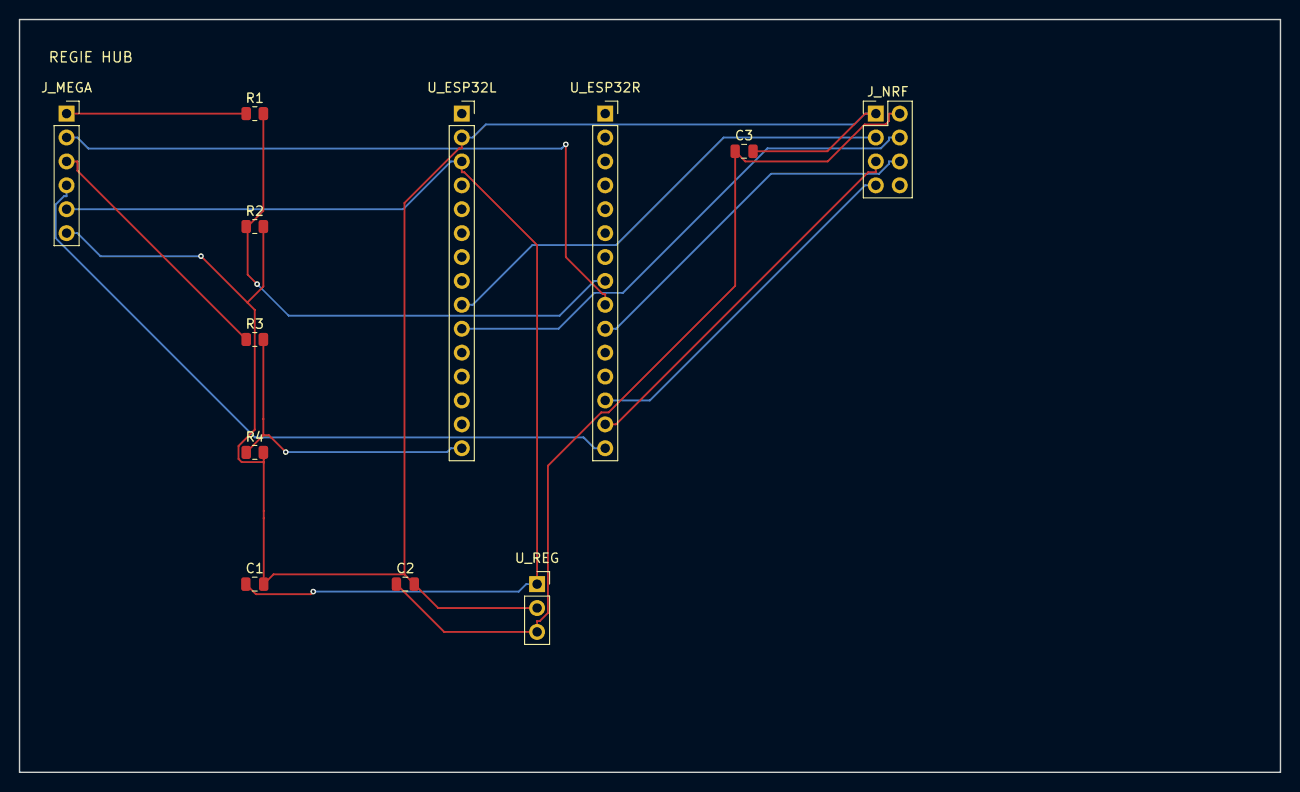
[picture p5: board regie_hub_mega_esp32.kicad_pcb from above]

Board: 2 copper layers, 134.0 x 80.0 mm, 12 parts (0 on the bottom side), 14 nets.

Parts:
C1: ~10uF decouplage entree regulateur - CMS; C_0805_2012Metric
C2: ~10uF decouplage sortie regulateur - CMS; C_0805_2012Metric
C3: 10-100uF decouplage nRF24 (obligatoire, au plus p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; C_0805_2012Metric
J_MEGA: Vers Mega: TX2(16) RX2(17) TX1(18) RX1(19) 5V GND; PinSocket_1x06_P2.54mm_Vertical
J_NRF: nRF24L01+PA+LNA (broches MALES, le module a des p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; PinHeader_2x04_P2.54mm_Vertical
R1: 1k (diviseur TX2, serie) - CMS; R_0805_2012Metric
R2: 2k (diviseur TX2, vers GND) - CMS; R_0805_2012Metric
R3: 1k (diviseur TX3, serie) - CMS; R_0805_2012Metric
R4: 2k (diviseur TX3, vers GND) - CMS; R_0805_2012Metric
U_ESP32L: ESP32 DevKit V1 colonne gauche (broches 1-15); PinSocket_1x15_P2.54mm_Vertical
U_ESP32R: ESP32 DevKit V1 colonne droite (broches 16-30); PinSocket_1x15_P2.54mm_Vertical
U_REG: Regulateur 3.3V dedie (ex AMS1117-3.3); PinSocket_1x03_P2.54mm_Vertical

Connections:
ESP32_RX1_3V3: R1.2, R2.1, U_ESP32R.23
ESP32_RX2_3V3: R3.2, R4.1, U_ESP32L.15
GND: C1.2, C2.2, C3.2, J_MEGA.6, J_NRF.1, R2.2, R4.2, U_ESP32L.2, U_REG.2
MEGA_RX2_DIRECT: J_MEGA.2, U_ESP32R.22
MEGA_RX3_DIRECT: J_MEGA.4, U_ESP32R.16
MEGA_TX2_5V: J_MEGA.1, R1.1
MEGA_TX3_5V: J_MEGA.3, R3.1
NRF_CE: J_NRF.3, U_ESP32L.9
NRF_CSN: J_NRF.4, U_ESP32L.10
NRF_MISO: J_NRF.7, U_ESP32R.18
NRF_MOSI: J_NRF.6, U_ESP32R.21
NRF_SCK: J_NRF.5, U_ESP32R.17
NRF_VCC_DEDIE: C2.1, C3.1, J_NRF.2, U_REG.3
VCC_5V_MEGA: C1.1, J_MEGA.5, U_ESP32L.3, U_REG.1

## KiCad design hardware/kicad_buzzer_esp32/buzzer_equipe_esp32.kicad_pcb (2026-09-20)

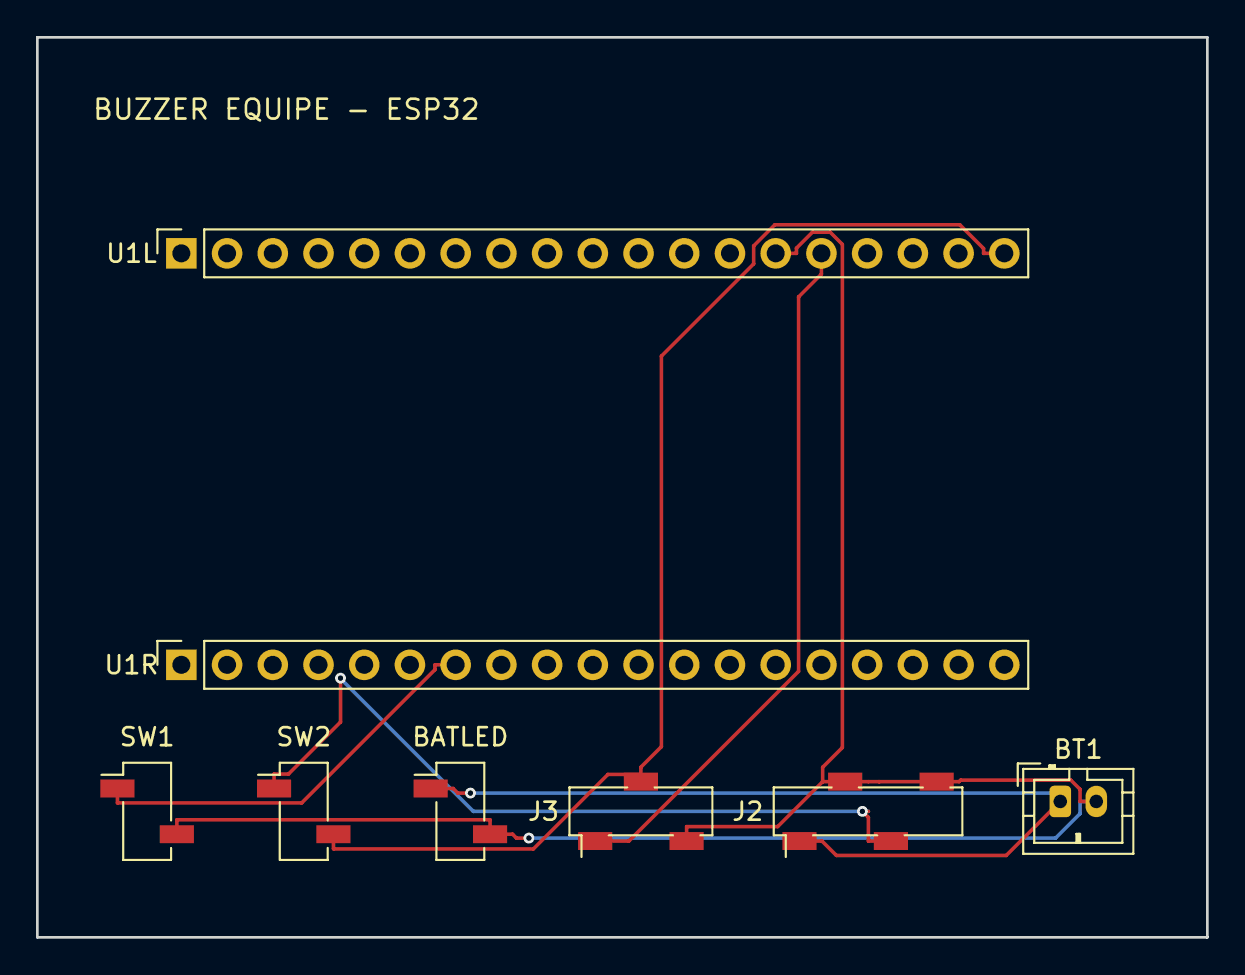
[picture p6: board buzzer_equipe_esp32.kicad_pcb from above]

Board: 2 copper layers, 65.0 x 50.0 mm, 8 parts (0 on the bottom side), 6 nets.

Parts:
BATLED: Indicateur niveau batterie (4 LED) - CMS - 1=B+ 2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; PinSocket_1x02_P2.54mm_Vertical_SMD_Pin1Left
BT1: Batterie LiPo 1S 1000-1200mAh - connecteur JST-PH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; JST_PH_B2B-PH-K_1x02_P2.00mm_Vertical
J2: Module charge TP4056+protect+boost USB-C - CMS; PinSocket_1x04_P2.54mm_Vertical_SMD_Pin1Left
J3: Module vibreur IN/VCC/GND - CMS; PinSocket_1x03_P2.54mm_Vertical_SMD_Pin1Left
SW1: Bouton BUZZ (fils volants) - CMS; PinSocket_1x02_P2.54mm_Vertical_SMD_Pin1Left
SW2: Interrupteur marche/arret (fils volants) - CMS; PinSocket_1x02_P2.54mm_Vertical_SMD_Pin1Left
U1L: ESP32 colonne gauche (broches 1-19) - VERIFIER su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; PinSocket_1x19_P2.54mm_Vertical
U1R: ESP32 colonne droite (broches 20-38) - VERIFIER s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; PinSocket_1x19_P2.54mm_Vertical

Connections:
BAT_PLUS: BATLED.1, BT1.1, J2.1
BTN_SIG: SW1.1, U1R.32
GND: BATLED.2, BT1.2, J2.2, J2.4, J3.3, SW1.2, U1L.14
VCC_5V_RAW: J2.3, SW2.1
VCC_5V_SW: J3.2, SW2.2, U1L.19
VIBE_IN: J3.1, U1L.15

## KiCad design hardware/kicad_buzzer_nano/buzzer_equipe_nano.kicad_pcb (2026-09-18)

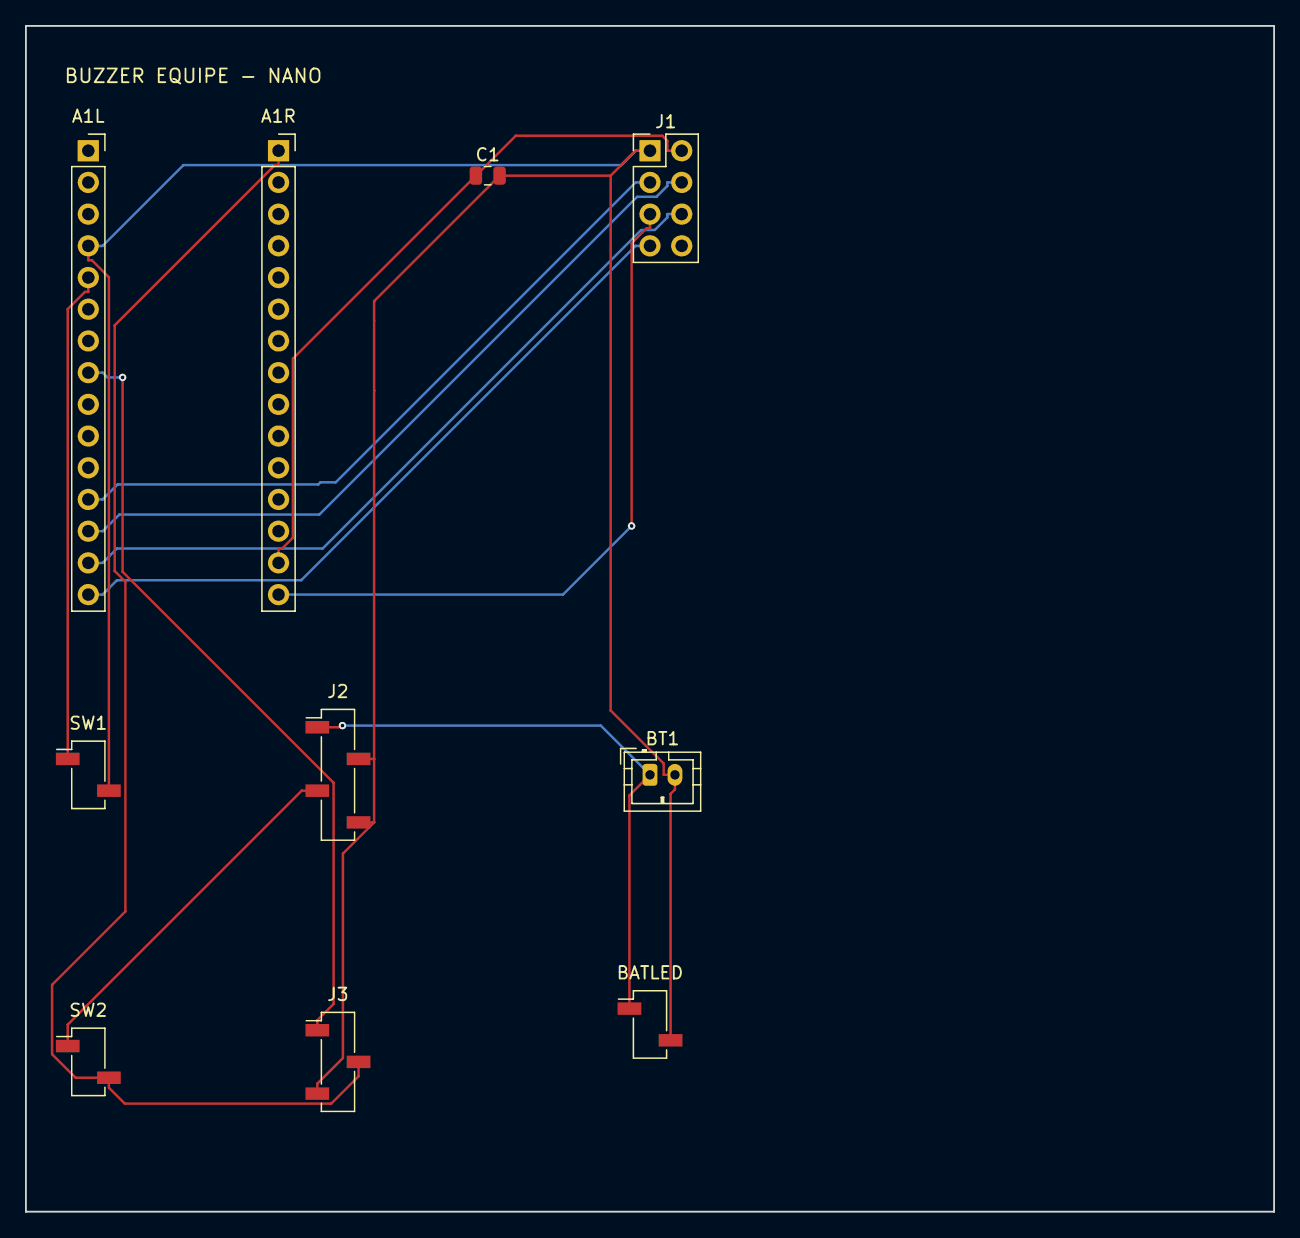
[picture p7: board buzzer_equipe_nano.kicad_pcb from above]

Board: 2 copper layers, 100.0 x 95.0 mm, 10 parts (0 on the bottom side), 12 nets.

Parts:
A1L: Nano colonne gauche (broches 1-15); PinSocket_1x15_P2.54mm_Vertical
A1R: Nano colonne droite (broches 16-30); PinSocket_1x15_P2.54mm_Vertical
BATLED: Indicateur niveau batterie (4 LED) - CMS - 1=B+ 2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; PinSocket_1x02_P2.54mm_Vertical_SMD_Pin1Left
BT1: Batterie LiPo 1S 500-600mAh - connecteur JST-PH (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; JST_PH_B2B-PH-K_1x02_P2.00mm_Vertical
C1: 10-100uF decouplage nRF24 (obligatoire, au plus p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; C_0805_2012Metric
J1: nRF24L01+PA+LNA (broches MALES, le module a des p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; PinHeader_2x04_P2.54mm_Vertical
J2: Module charge TP4056+protect+boost USB-C - CMS; PinSocket_1x04_P2.54mm_Vertical_SMD_Pin1Left
J3: Module vibreur IN/VCC/GND - CMS; PinSocket_1x03_P2.54mm_Vertical_SMD_Pin1Left
SW1: Bouton BUZZ (fils volants) - CMS; PinSocket_1x02_P2.54mm_Vertical_SMD_Pin1Left
SW2: Interrupteur marche/arret (fils volants) - CMS; PinSocket_1x02_P2.54mm_Vertical_SMD_Pin1Left

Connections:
+3V3: A1R.17, C1.1, J1.2
BAT_PLUS: BATLED.1, BT1.1, J2.1
BTN_SIG: A1L.5, SW1.1
GND: A1L.4, BATLED.2, BT1.2, C1.2, J1.1, J2.2, J2.4, J3.3, SW1.2
NRF_CE: A1L.12, J1.3
NRF_CSN: A1L.13, J1.4
NRF_MISO: A1L.15, J1.7
NRF_MOSI: A1L.14, J1.6
NRF_SCK: A1R.16, J1.5
VCC_5V_RAW: J2.3, SW2.1
VCC_5V_SW: A1R.30, J3.2, SW2.2
VIBE_IN: A1L.8, J3.1

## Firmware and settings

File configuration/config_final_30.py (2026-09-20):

import copy
import dearpygui.dearpygui as dpg
import json
import os
import queue
import sys
import serial
import serial.tools.list_ports
import threading
import time
from datetime import datetime
import re

# --- CONFIGURATION & FICHIERS ---
def _dossier_config():
    """Dossier ou lire/ecrire config_quiz_pro.json.

    [FIX] Avec l'exe PyInstaller (--onefile), __file__ pointe vers un dossier
    TEMPORAIRE (_MEIxxxx) supprime a la fermeture : la config etait ecrite la,
    puis perdue a chaque fois -> "ca reprend au debut". On utilise donc le
    dossier de l'executable (comme interface_30eq.py), ou, s'il n'est pas
    modifiable (ex. Program Files), un dossier "QuizDMX" dans le dossier de
    l'utilisateur.
    """
    if getattr(sys, "frozen", False):
        dossier = os.path.dirname(os.path.abspath(sys.executable))
        if not os.access(dossier, os.W_OK):
            dossier = os.path.join(os.path.expanduser("~"), "QuizDMX")
            os.makedirs(dossier, exist_ok=True)
        return dossier
    return os.path.dirname(os.path.abspath(__file__))


BASE_DIR = _dossier_config()
CONFIG_FILE = os.path.join(BASE_DIR, "config_quiz_pro.json")
ser = None

# Mises à jour UI depuis le thread de synchro (Dear PyGui : éviter dpg.* hors fil principal)
_ui_queue = queue.Queue()


def schedule_ui(fn):
    _ui_queue.put(fn)


def schedule_progress_bar(step: int, total: int):
    def fn():
        if total <= 0 or not dpg.does_item_exist("progress_bar"):
            return
        dpg.set_value("progress_bar", step / total)

    schedule_ui(fn)


def drain_ui_queue():
    while True:
        try:
            fn = _ui_queue.get_nowait()
        except queue.Empty:
            break
        try:
            fn()
        except Exception:
            pass

# VID USB connus des adaptateurs Arduino/USB-série (même liste que interface_30eq.py)
KNOWN_ARDUINO_VIDS = [0x2341, 0x2A03, 0x1A86, 0x10C4, 0x0403]

def get_clean_ports():
    """Scanne les ports USB sur Windows, Mac et Linux, en filtrant les faux
    positifs Bluetooth (cu.Bluetooth-Incoming-Port, cu.MALS, description
    contenant BLUETOOTH/INCOMING-PORT) qui perturbent la detection sous
    Mac/Linux, et en priorisant les VID Arduino connus."""
    try:
        all_ports = serial.tools.list_ports.comports()
    except Exception as e:
        # Ne jamais bloquer l'interface si la detection echoue
        return [f"ERREUR SCAN PORTS : {e}"]

    clean_list = []
    ftdi_sans_driver_suspect = False
    aucune_carte_trouvee = True

    for p in all_ports:
        desc = (p.description or "").upper()
        device = p.device
        hwid = (p.hwid or "").upper()
        vid = p.vid

        # Détection USB par description
        is_usb = any(k in desc for k in ["USB", "ARDUINO", "CH340", "CP210", "FTDI", "UART", "SERIAL"])

        # Priorité aux VID Arduino/USB-série connus (plus fiable que la description)
        if vid in KNOWN_ARDUINO_VIDS:
            is_usb = True
        if any(f"VID_{v:04X}" in hwid for v in KNOWN_ARDUINO_VIDS):
            is_usb = True

        # Mac : /dev/cu.usbserial ou /dev/cu.usbmodem
        if device.startswith("/dev/cu.usbserial") or device.startswith("/dev/cu.usbmodem"):
            is_usb = True

        # Linux : /dev/ttyUSB ou /dev/ttyACM
        if device.startswith("/dev/ttyUSB") or device.startswith("/dev/ttyACM"):
            is_usb = True

        # Exclusions Bluetooth : chemins Mac connus ET description (couvre
        # aussi les ports virtuels Bluetooth qui n'utilisent pas ces chemins,
        # ex. certains rfcomm Linux ou nouveaux noms macOS)
        is_bluetooth = (
            device.startswith("/dev/cu.Bluetooth")
            or device.startswith("/dev/cu.MALS")
            or "BLUETOOTH" in desc
            or "INCOMING-PORT" in desc
        )
        if is_bluetooth:
            is_usb = False

        # Windows : COM1 est quasi toujours un port systeme, jamais l'Arduino
        if device.upper() == "COM1":
            is_usb = False

        if is_usb:
            clean_list.append(f"{device} (USB)")
            aucune_carte_trouvee = False
        elif is_bluetooth:
            clean_list.append(f"{device} (Bluetooth - ignore)")
        else:
            clean_list.append(f"{device} (Interne)")

        # Carte FTDI visible par description mais VID inattendu -> pilote
        # VCP probablement absent (frequent sur macOS recent)
        if "FTDI" in desc and vid != 0x0403:
            ftdi_sans_driver_suspect = True

    if not clean_list:
        return ["AUCUN PORT DÉTECTÉ"]

    # schedule_ui() : get_clean_ports() peut tourner hors du thread principal
    # (scan en arriere-plan, voir refresh_ports()) -> jamais de dpg.* direct ici.
    if ftdi_sans_driver_suspect:
        schedule_ui(lambda: log(
            "Carte FTDI detectee sans VID standard : installer le pilote FTDI VCP si la connexion echoue.",
            color=[255, 200, 0]))
    elif aucune_carte_trouvee:
        schedule_ui(lambda: log(
            "Aucune carte Arduino/USB-serie detectee : verifier le cable, ou installer le pilote "
            "(FTDI VCP / CH340 / CP210x selon l'adaptateur, frequent sur macOS recent).",
            color=[255, 200, 0]))

    return clean_list

def log(message, color=[255, 255, 255]):
    if dpg.does_item_exist("log_list"):
        timestamp = datetime.now().strftime("%H:%M:%S")
        dpg.add_text(f"[{timestamp}] {message}", parent="log_list", color=color)
        dpg.set_y_scroll("log_child", dpg.get_y_scroll_max("log_child") + 50)

_ports_scanning = False

def refresh_ports():
    """Scanne les ports en arriere-plan : serial.tools.list_ports.comports()
    peut se bloquer plusieurs secondes quand le Bluetooth est actif (ports
    virtuels cu.Bluetooth-Incoming-Port / rfcomm), ce qui gelait toute
    l'interface Dear PyGui pendant le scan (thread principal)."""
    global _ports_scanning
    if _ports_scanning:
        return
    _ports_scanning = True
    if dpg.does_item_exist("btn_refresh_ports"):
        dpg.configure_item("btn_refresh_ports", enabled=False)

    def worker():
        global _ports_scanning
        ports = get_clean_ports()

        def apply():
            global _ports_scanning
            _ports_scanning = False
            if dpg.does_item_exist("btn_refresh_ports"):
                dpg.configure_item("btn_refresh_ports", enabled=True)
            if dpg.does_item_exist("port_combo"):
                dpg.configure_item("port_combo", items=ports)

        schedule_ui(apply)

    threading.Thread(target=worker, daemon=True).start()

# Profil de canaux par defaut pour un nouveau projecteur -- chaque
# projecteur garde desormais son PROPRE reglage (voir migration ci-dessous),
# ce qui permet de melanger des modeles differents (projecteur RGB simple,
# lyre utilisee juste pour sa couleur, etc.) sans jamais toucher au code.
FIXTURE_PROFILE_DEFAULTS = {
    "nb_canaux": 8,
    "off_dim": 0,
    "off_r": 1,
    "off_g": 2,
    "off_b": 3,
    "off_strobe": -1,    # -1 = pas de canal strobe (depend du projecteur)
    "strobe_value": 200, # valeur qui declenche le strobe (depend du projecteur)
    "strobe_repos": 0,   # valeur du canal strobe HORS strobe : 0 normalement,
                         # mais certaines lyres combinent obturateur+strobe sur
                         # le meme canal -- mettre ~255 pour elles (sinon la
                         # lumiere reste noire une fois le strobe termine)
    "mode": 0,           # 0 = RGB continu (off_r/off_g/off_b independants)
                         # 1 = roue de couleurs (off_r = canal unique de la
                         # roue, off_g/off_b ignores) -- pour les lyres
}


def load_config():
    """Charge la configuration et assure la compatibilité des données."""
    default_structure = {
        "equipes": [{"couleurs": [[255, 255, 255]]}],
        "groupes_dmx": [{"id": 1, "adresse": 1, **FIXTURE_PROFILE_DEFAULTS}],
    }

    try:
        with open(CONFIG_FILE, 'r', encoding='utf-8') as f:
            data = json.load(f)
    except FileNotFoundError:
        return copy.deepcopy(default_structure)
    except json.JSONDecodeError as e:
        print(f"Erreur config JSON: {e}")
        return copy.deepcopy(default_structure)
    except Exception as e:
        print(f"Erreur config: {e}")
        return copy.deepcopy(default_structure)

    if not isinstance(data, dict):
        return copy.deepcopy(default_structure)

    if "groupes_dmx" not in data or not isinstance(data["groupes_dmx"], list) or not data["groupes_dmx"]:
        data["groupes_dmx"] = copy.deepcopy(default_structure["groupes_dmx"])
    if "equipes" not in data or not isinstance(data["equipes"], list) or not data["equipes"]:
        data["equipes"] = copy.deepcopy(default_structure["equipes"])

    # Migration : une ancienne config avait un seul reglage "dmx_universal"
    # partage par tous les projecteurs -- on l'utilise comme valeur de
    # depart pour chaque projecteur plutot que le defaut generique, pour
    # ne rien perdre des reglages deja en place.
    ancien_universel = data.get("dmx_universal")
    valeurs_depart = FIXTURE_PROFILE_DEFAULTS
    if isinstance(ancien_universel, dict):
        valeurs_depart = {**FIXTURE_PROFILE_DEFAULTS, **{
            k: ancien_universel[k] for k in FIXTURE_PROFILE_DEFAULTS if k in ancien_universel
        }}
    data.pop("dmx_universal", None)

    for grp in data["groupes_dmx"]:
        if not isinstance(grp, dict):
            continue
        for k, v in valeurs_depart.items():
            grp.setdefault(k, v)

    for eq in data["equipes"]:
        if not isinstance(eq, dict):
            continue
        if "couleurs" not in eq or not isinstance(eq["couleurs"], list):
            eq["couleurs"] = [[255, 255, 255] for _ in data["groupes_dmx"]]
        while len(eq["couleurs"]) < len(data["groupes_dmx"]):
            eq["couleurs"].append([255, 255, 255])
        # Duree du strobe a l'annonce du gagnant, PAR EQUIPE : 0 = aucun,
        # -1 = continu, >0 = duree en ms. Absent par defaut (pas de strobe)
        # tant que l'operateur ne l'active pas explicitement pour l'equipe.
        eq.setdefault("strobe_duree_ms", 0)

    return data

config = load_config()

def save_config():
    with open(CONFIG_FILE, 'w', encoding='utf-8') as f:
        json.dump(config, f, indent=2)

# --- LOGIQUE DMX ---
def auto_adressage():
    """Recalcule les adresses en chainant chaque projecteur selon SON
    propre nombre de canaux -- fonctionne meme avec des projecteurs de
    modeles differents (ex: un simple RGB a 8 canaux suivi d'une lyre a
    16 canaux avancera correctement de 16, pas d'un pas unique partage)."""
    if not config["groupes_dmx"]: return
    addr = config["groupes_dmx"][0]["adresse"]
    for grp in config["groupes_dmx"]:
        grp["adresse"] = addr
        addr += grp.get("nb_canaux", FIXTURE_PROFILE_DEFAULTS["nb_canaux"])
    save_config()
    refresh_ui_full()
    log("Adressage auto genere (chaine selon les canaux de chaque projecteur).", color=[0, 255, 255])

# ========== FONCTIONS AJOUT/SUPPRESSION PROJECTEURS ==========
def add_projector():
    """Ajoute un nouveau projecteur. MAX 30. Reprend le profil de canaux
    du dernier projecteur existant comme point de depart (souvent le
    meme modele que celui d'a cote), plutot que le defaut generique."""
    if len(config["groupes_dmx"]) >= 30:
        log("Maximum 30 projecteurs !", color=[255, 50, 50])
        return
    new_id = len(config["groupes_dmx"]) + 1
    profil_depart = FIXTURE_PROFILE_DEFAULTS
    if config["groupes_dmx"]:
        dernier = config["groupes_dmx"][-1]
        profil_depart = {k: dernier.get(k, v) for k, v in FIXTURE_PROFILE_DEFAULTS.items()}
    config["groupes_dmx"].append({"id": new_id, "adresse": 1, **profil_depart})

    for eq in config["equipes"]:
        eq["couleurs"].append([255, 255, 255])

    save_config()
    refresh_ui_full()
    log(f"Projecteur {new_id} ajoute", color=[0, 255, 0])

def remove_projector():
    """Supprime le dernier projecteur."""
    if len(config["groupes_dmx"]) > 1:
        removed = config["groupes_dmx"].pop()
        
        for eq in config["equipes"]:
            if eq["couleurs"]:
                eq["couleurs"].pop()
        
        save_config()
        refresh_ui_full()
        log(f"Projecteur {removed['id']} supprime", color=[255, 150, 0])
    else:
        log("Impossible de supprimer le dernier projecteur", color=[255, 100, 0])

def reset_total_config():
    config["groupes_dmx"] = [{"id": 1, "adresse": 1, **FIXTURE_PROFILE_DEFAULTS}]
    config["equipes"] = [{"couleurs": [[255, 255, 255]]}]
    save_config()
    refresh_ui_full()
    log("Configuration reinitialisee par defaut.", color=[255, 100, 100])

def verifier_et_sauver():
    save_config()
    log("Configuration sauvegardee sur le PC.", color=[0, 255, 0])

# --- COMMUNICATIONS ---
def envoyer_configuration_complete():
    global ser
    if not ser or not ser.is_open:
        log("ERREUR : Arduino non connecte !", color=[255, 50, 50])
        return

    for i, grp in enumerate(config["groupes_dmx"]):
        adr = grp["adresse"]
        nb_canaux = grp.get("nb_canaux", FIXTURE_PROFILE_DEFAULTS["nb_canaux"])
        if adr < 1 or adr > 512:
            log(f"Erreur Proj {i+1} : Adresse {adr} invalide", color=[255, 0, 0])
            return
        if (adr + nb_canaux - 1) > 512:
            log(f"Erreur Proj {i+1} : Fin canal {adr + nb_canaux - 1} > 512", color=[255, 0, 0])
            return

    # Ce qui part vers la Mega doit aussi etre garde sur le PC.
    save_config()

    def thread_sync():
        try:
            def ui_start():
                if dpg.does_item_exist("progress_group"):
                    dpg.show_item("progress_group")
                if dpg.does_item_exist("progress_bar"):
                    dpg.set_value("progress_bar", 0.0)
                log("Synchronisation MEGA...", color=[255, 165, 0])

            schedule_ui(ui_start)

            ser.reset_input_buffer()
            time.sleep(0.2)

            # +1 palier de progression par projecteur, un SET_PATCH est
            # desormais envoye individuellement pour chacun (profil propre).
            # +1 palier par equipe pour SET_STROBE_EQ, en plus des patchs
            # par projecteur, des adresses, et des couleurs par equipe/projecteur.
            total_steps = (1 + len(config["groupes_dmx"]) + len(config["groupes_dmx"])
                           + (len(config["equipes"]) * len(config["groupes_dmx"]))
                           + len(config["equipes"]))
            current_step = 0

            for i, grp in enumerate(config["groupes_dmx"]):
                trame_patch = (f"SET_PATCH:{i}:{grp['nb_canaux']}:{grp['off_dim']}:{grp['off_r']}:{grp['off_g']}:"
                               f"{grp['off_b']}:{grp['off_strobe']}:{grp['strobe_value']}:"
                               f"{grp.get('strobe_repos', FIXTURE_PROFILE_DEFAULTS['strobe_repos'])}:"
                               f"{grp.get('mode', FIXTURE_PROFILE_DEFAULTS['mode'])}\n")
                ser.write(trame_patch.encode())
                current_step += 1
                schedule_progress_bar(current_step, total_steps)
                time.sleep(0.08)

            ser.write(f"SET_NB_EQ:{len(config['equipes'])}\n".encode())
            current_step += 1
            schedule_progress_bar(current_step, total_steps)
            time.sleep(0.1)

            for i, grp in enumerate(config["groupes_dmx"]):
                ser.write(f"SET_ADR:{i}:{grp['adresse']}\n".encode())
                current_step += 1
                schedule_progress_bar(current_step, total_steps)
                time.sleep(0.08)

            for e_idx, eq in enumerate(config["equipes"]):
                for g_idx, col in enumerate(eq["couleurs"]):
                    r, g, b = [max(0, min(255, int(c))) for c in col]
                    trame = f"SET_COL:{e_idx+1}:{g_idx}:{r}:{g}:{b}\n"
                    ser.write(trame.encode())
                    current_step += 1
                    schedule_progress_bar(current_step, total_steps)
                    time.sleep(0.05)

                duree = eq.get("strobe_duree_ms", 0)
                ser.write(f"SET_STROBE_EQ:{e_idx+1}:{duree}\n".encode())
                current_step += 1
                schedule_progress_bar(current_step, total_steps)
                time.sleep(0.05)

            ser.write(b"SAVE_CONFIG\n")
            schedule_ui(lambda: log("MEGA SYNCHRONISE !", color=[0, 255, 127]))
            time.sleep(0.5)
            
        except Exception as e:
            schedule_ui(lambda err=str(e): log(f"Erreur synchro : {err}", color=[255, 0, 0]))
        finally:
            def ui_done():
                if dpg.does_item_exist("progress_group"):
                    dpg.hide_item("progress_group")

            schedule_ui(ui_done)

    threading.Thread(target=thread_sync, daemon=True).start()

def parse_dump_mega(lignes):
    """Convertit les lignes CFG:... renvoyees par la Mega (GET_CONFIG) en
    (groupes_dmx, equipes) au format de config_quiz_pro.json. Leve ValueError
    si le dump est incomplet. Ce que la Mega ne stocke pas (rien d'autre que
    projecteurs, couleurs et strobes dans ce fichier) n'est pas concerne."""
    nb_eq = 0
    projs = {}
    strobes = {}
    couleurs = {}
    for ligne in lignes:
        p = ligne.strip().split(":")
        if len(p) < 3 or p[0] != "CFG":
            continue
        try:
            n = [int(v) for v in p[2:]]
        except ValueError:
            continue
        if p[1] == "NB_EQ":
            nb_eq = n[0]
        elif p[1] == "PROJ" and len(n) >= 11:
            projs[n[0]] = {
                "id": n[0] + 1, "adresse": n[1], "nb_canaux": n[2],
                "off_dim": n[3], "off_r": n[4], "off_g": n[5], "off_b": n[6],
                "off_strobe": n[7], "strobe_value": n[8], "strobe_repos": n[9],
                "mode": n[10],
            }
        elif p[1] == "STROBE" and len(n) >= 2:
            strobes[n[0] - 1] = n[1]
        elif p[1] == "COL" and len(n) >= 5:
            couleurs.setdefault(n[0] - 1, {})[n[1]] = [n[2], n[3], n[4]]

    if nb_eq < 1 or not projs:
        raise ValueError("configuration recue incomplete ou vide")

    groupes = [projs[i] for i in sorted(projs)]
    for i, grp in enumerate(groupes):
        grp["id"] = i + 1
    equipes = []
    for e in range(nb_eq):
        equipes.append({
            "couleurs": [couleurs.get(e, {}).get(g, [255, 255, 255]) for g in range(len(groupes))],
            "strobe_duree_ms": strobes.get(e, 0),
        })
    return groupes, equipes


def lire_configuration_mega():
    global ser
    if not ser or not ser.is_open:
        log("ERREUR : Arduino non connecte !", color=[255, 50, 50])
        return
    port = ser

    def thread_lecture():
        try:
            schedule_ui(lambda: log("Lecture de la configuration depuis la Mega...", color=[255, 165, 0]))
            port.reset_input_buffer()
            port.write(b"GET_CONFIG\n")
            lignes = []
            fin = time.time() + 15
            occupe = False
            termine = False
            while time.time() < fin:
                brut = port.readline().decode(errors="ignore").strip()
                if not brut:
                    continue
                if "GET_CONFIG_BUSY" in brut:
                    occupe = True
                    break
                if brut.startswith("CFG:"):
                    lignes.append(brut)
                    if brut == "CFG:END":
                        termine = True
                        break
            if occupe:
                schedule_ui(lambda: log("Mega en manche (buzz en cours) : valider/refuser puis relire.", color=[255, 150, 0]))
                return
            if not termine:
                schedule_ui(lambda: log("Aucune reponse complete de la Mega (firmware sans GET_CONFIG ?).", color=[255, 50, 50]))
                return
            groupes, equipes = parse_dump_mega(lignes)

            def appliquer():
                if os.path.exists(CONFIG_FILE):
                    try:
                        with open(CONFIG_FILE, 'r', encoding='utf-8') as f_in, \
                             open(CONFIG_FILE + ".bak", 'w', encoding='utf-8') as f_out:
                            f_out.write(f_in.read())
                    except OSError:
                        pass
                config["groupes_dmx"] = groupes
                config["equipes"] = equipes
                save_config()
                refresh_ui_full()
                log(f"Configuration lue depuis la Mega : {len(groupes)} projecteur(s), {len(equipes)} equipe(s). "
                    f"(ancienne config PC sauvegardee en .bak)", color=[0, 255, 127])

            schedule_ui(appliquer)
        except Exception as e:
            schedule_ui(lambda err=str(e): log(f"Erreur lecture Mega : {err}", color=[255, 0, 0]))

    threading.Thread(target=thread_lecture, daemon=True).start()
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

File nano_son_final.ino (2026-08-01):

#include <SPI.h>
#include <nRF24L01.h>
#include <RF24.h>
#include <SoftwareSerial.h>
#include <DFRobotDFPlayerMini.h>
#include <string.h>
#include <stdlib.h>

static void dfPlayTrack(DFRobotDFPlayerMini &df, uint8_t track);
static void dfStopTrack(DFRobotDFPlayerMini &df);
static void drainDfSerial(DFRobotDFPlayerMini &df, uint16_t totalMs);
static bool dfErreurPisteAbsent(uint16_t par);
static void jouerBuzzEquipeOuGenerique(DFRobotDFPlayerMini &df, uint8_t team);
static void pollRadioRx(void);
static bool dfProbeTrackMissing(DFRobotDFPlayerMini &df, uint8_t track, uint16_t maxMs);
static void sonProbeSdAtBoot(DFRobotDFPlayerMini &df);

/** Delais DF / radio (latence vs fiabilite). */
#define DF_ERR_POLL_MS      100
#define DF_PROBE_BOOT_MS     55
#define DF_DRAIN_SHORT_MS    28
#define DF_DRAIN_CMD_MS      40
/** Volume DFPlayer 0..30 (modifier pour le client si besoin). */
#define DF_VOLUME           25

/** Paquet radio Mega → nano (pipe 00002), 4 octets, NO_ACK. */
struct SonPayload {
    uint16_t cmd;
    uint8_t team;
    uint8_t seq;
};

#define SON_RX_Q_LEN 12
/** Re-arme l'ecoute PRX (filet si SPI/DF a laisse le chip hors RX). */
#define SON_REARM_LISTEN_MS 400
static SonPayload sonRxQ[SON_RX_Q_LEN];
static uint8_t sonRxQHead = 0;
static uint8_t sonRxQTail = 0;

static void playSonCmd(uint16_t cmd, uint8_t team);
static void traiterPaquetSonRadio(const SonPayload &p);
static void forwardSonToPc(uint16_t cmd, uint8_t team);
static void parseSerialLine(char *line);
static void radioSendCmdToBuzzers(uint8_t value);

// =========================================================
// CONFIGURATION
// =========================================================
RF24 radio(9, 10);

// Pipe "00002" : ordres son depuis la Mega (SonPayload).
// Pipe "00001" : relais RESET_ALL/RELANCE_PARTIEL vers les buzzers, depuis le PC (mode 3, Mega non branchée en série).
// Usage client : alimentation seule (pas de USB PC) — cérémonies sans ordinateur.
// Avec PC : la Mega envoie la même radio ; le logiciel peut jouer sur le PC si le nano est éteint (AUDIO_PC).
const byte adresseSon[6]     = "00002";
const byte adresseBuzzers[6] = "00001";

/** Même format que megaf.ino / nano_animateur (CMD 88 = relance, 99 = reset). */
struct RadioMsg {
    uint8_t kind;   // 2 = CMD
    uint8_t value;  // 88 / 99
    uint16_t seq;
};
static uint16_t seqOutboundCmd = 0;

#define RADIO_CHANNEL 108

bool radioOK = false;
bool mp3OK   = false;
unsigned long dernierBattement = 0;
unsigned long ledPulseUntil = 0;
/** Equipes 1..30 : bit i-1 = 1 si 01ii.mp3 a deja joue sans erreur (buzz plus rapide ensuite). */
static uint32_t teamTrackKnownOk = 0;

// ----- Port USB (PC, mode 3) : score + option AUDIO_PC (sons sur PC, DFPlayer muet pour eviter doublon) -----
#define SERIAL_BUF_LEN 80
static char serialBuf[SERIAL_BUF_LEN];
static uint8_t serialLen = 0;
/** Si true : ordres son recus par radio depuis la Mega sont renvoyes en USB (FWD_SON:...) sans jouer le DF. */
static bool audioViaPc = false;

/** Relaie RESET_ALL/RELANCE_PARTIEL vers les buzzers radio (pipe 00001), si la Mega n'est pas branchee en serie. */
static void radioSendCmdToBuzzers(uint8_t value) {
    if (!radioOK) return;
    RadioMsg msg = {2, value, (uint16_t)(++seqOutboundCmd)};
    radio.stopListening();
    radio.openWritingPipe(adresseBuzzers);
    radio.write(&msg, sizeof(msg));
    radio.startListening();
}

// DFPlayer sur broches D4 (TX) et D5 (RX)
SoftwareSerial mySoftwareSerial(5, 4); // RX=D5, TX=D4
DFRobotDFPlayerMini monLecteurMP3;

// =========================================================
// Dossier « mp3 » à la racine de la carte : fichiers nommés 0001.mp3, 0002.mp3, 0101.mp3, etc.
// La lib DFRobot utilise playMp3Folder(N) : N = numero sans zeros de tete (1 -> 0001, 101 -> 0101).
// Ne pas utiliser play(N) : c’est l’index d’ordre sur la carte, pas le nom du fichier.

/** Filtre bruit RF / taille paquet incorrecte (Mega = 4 octets, cmd 200/201/202). */
static bool sonPayloadValide(const SonPayload &p) {
    if (p.cmd != 200 && p.cmd != 201 && p.cmd != 202) return false;
    if (p.cmd == 200 && p.team > 30) return false;
    return true;
}

/** Dédoublonne retransmissions Mega (meme seq). */
static bool dedupeSonRadio(const SonPayload &p) {
    const unsigned long now = millis();
    static uint16_t dedupeCmd = 0xFFFFu;
    static uint8_t dedupeTeam = 0xFFu;
    static uint8_t dedupeSeq = 0xFFu;
    static unsigned long dedupeAtMs = 0;
    const unsigned long windowMs = (p.cmd == 200) ? 520UL : 420UL;
    if (p.cmd == dedupeCmd && p.team == dedupeTeam && p.seq == dedupeSeq &&
        (now - dedupeAtMs) < windowMs) {
        return true;
    }
    dedupeCmd = p.cmd;
    dedupeTeam = p.team;
    dedupeSeq = p.seq;
    dedupeAtMs = now;
    return false;
}

static bool sonRxQueuePush(const SonPayload &p) {
    uint8_t next = (uint8_t)((sonRxQTail + 1) % SON_RX_Q_LEN);
    if (next == sonRxQHead) {
        sonRxQHead = (uint8_t)((sonRxQHead + 1) % SON_RX_Q_LEN);
    }
    sonRxQ[sonRxQTail] = p;
    sonRxQTail = next;
    return true;
}

static bool sonRxQueuePop(SonPayload &out) {
    if (sonRxQHead == sonRxQTail) return false;
    out = sonRxQ[sonRxQHead];
    sonRxQHead = (uint8_t)((sonRxQHead + 1) % SON_RX_Q_LEN);
    return true;
}

static void ledPulseUpdate(void) {
    if (ledPulseUntil != 0 && (long)(millis() - ledPulseUntil) >= 0) {
        digitalWrite(LED_BUILTIN, LOW);
        ledPulseUntil = 0;
    }
}

static void ledFlashMs(uint8_t ms) {
    digitalWrite(LED_BUILTIN, HIGH);
    ledPulseUntil = millis() + (unsigned long)ms;
}

/** Mode AUDIO_PC : relaie l'ordre son recu par radio vers le PC au lieu de jouer sur le DF. */
static void forwardSonToPc(uint16_t cmd, uint8_t team) {
    if (cmd == 200) {
        Serial.print(F("FWD_SON:200:"));
        Serial.println((unsigned int)team);
    } else if (cmd == 201) {
        Serial.println(F("FWD_SON:201"));
    } else if (cmd == 202) {
        Serial.println(F("FWD_SON:202"));
    }
}

/** Traite un paquet radio SonPayload (un par appel — evite blocage DF trop long). */
static void traiterPaquetSonRadio(const SonPayload &p) {
    if (p.cmd != 200 && p.cmd != 201 && p.cmd != 202) return;
    if (audioViaPc) {
        forwardSonToPc(p.cmd, p.team);
    } else {
        playSonCmd(p.cmd, p.team);
    }
}

static void pollRadioRx(void) {
    if (!radioOK) return;
    SonPayload rx;
    while (radio.available()) {
        radio.read(&rx, sizeof(rx));
        if (!sonPayloadValide(rx)) continue;
        if (dedupeSonRadio(rx)) continue;
        sonRxQueuePush(rx);
    }
}

static void drainSonRxQueue(uint8_t maxPackets) {
    SonPayload p;
    for (uint8_t n = 0; n < maxPackets && sonRxQueuePop(p); n++) {
        traiterPaquetSonRadio(p);
    }
}
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

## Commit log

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2026-05-09 Fix sounds stopping on validation; non-blocking DMX flash on MEGA
    [interface_30eq.py, mega30Equipe.ino]
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2026-05-14 Son radio: buzz 200 fiable, dédup 201/202, renfort WDT Mega
    - mega30Equipe: envoi simple pour cmd 200, double envoi pour 201/202;
    wdt_reset autour radio/série/EEPROM; limite traitement série et vidage FIFO.
    - nano_son_final: dédoublonnage seulement 201/202; helpers DFPlayer (play/stop
    avec pause radio), buzz équipe avec repli 0001 si piste absente.
    - test_radio_son: sketches Mega/Nano d’essai et README alignés sur le protocole.
    [mega30Equipe.ino, mega_test_son_tx.ino, nano_son_final.ino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]
2026-05-14 Doc modes, fix DF playMp3Folder, interface nano/score, fiabilité radio
    [interface_30eq.py, mega30Equipe.ino, nano_son_final.ino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]
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2026-08-01 Renomme mega30Equipe->megaf et nano_equipe_corrige->buzzer_nano_equipe, restaure le protocole série du nano son
    - megaf.ino : renommage + durcissement (watchdog, dédoublonnage radio, diagnostic ALIVE/IGNORED)
    - nano_son_final.ino : restaure le protocole USB (WHO/AUDIO_PC/AUDIO_DF/FWD_SON/CMD_SENT) perdu lors d'une édition précédente, cassant le Mode 3
    - ajout compile_arduino.sh (compilation via arduino-cli) et docs/ (explications HTML des sketches Mega/Nano)
    - MODES.md, README.md, interface_30eq.py : mises à jour de doc et de l'interface
    - .arduino-cli/ (cache local du toolchain) ignoré désormais
    [buzzer_nano_equipe.ino, interface_30eq.py, megaf.ino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]
2026-08-09 Nouvelle architecture radio : RF-Nano en pont, plus de nRF24 sur le Mega
    Le Mega n'a plus aucun module radio/SPI connecté (source du gel
    intermittent diagnostiqué en conditions réelles). Toute la réception
    nRF24 (équipes + animateur) est déportée sur un RF-Nano dédié
    (Nano + nRF24 intégrés d'usine, sans câblage Dupont), relié au Mega
    par une simple liaison série filaire (Serial2, 19200 bauds).
    - megaf.ino : retire RF24/nRF24L01, ajoute la lecture des lignes
    BUZZ:/CMD: venant du RF-Nano ; fix watchdog démarrage (capture et
    désactivation de MCUSR en section .init3, évite une boucle de reset)
    - nano_animateur_final.ino : émet désormais sur la même adresse que
    les équ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
    [megaf.ino, nano_animateur_final.ino, rf_nano_bridge.ino]
2026-08-09 Restaure le mode sans PC dans la nouvelle architecture RF-Nano
    Le Mega n'ayant plus de radio directe, le mode 1 (sans PC) avait besoin
    d'un nouveau chemin pour les ordres son :
    - megaf.ino : relaie SON:200/201/202 vers le RF-Nano (Serial2) en plus
    des messages PC_SERIAL existants, aux mêmes points de déclenchement
    qu'avant (buzz accepté, RESET_ALL, RELANCE_PARTIEL)
    - rf_nano_bridge.ino : ajoute envoyerSon()/updateRadioSonAsynchrone(),
    portées depuis l'ancien megaf.ino, pour retransmettre ces ordres en
    radio au nano son (pipe 00002) sans bloquer la réception des buzz
    équipes ; parseLigneMega() comprend maintenant SON:<cmd>:<team>
    - MODES.md / README.md : documentation mise à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
    [megaf.ino, rf_nano_bridge.ino]
2026-08-22 Durcit le pont RF-Nano/Mega contre les figements et ajoute l'effet strobe
    - rf_nano_bridge.ino : watchdog, debug serie desactive par defaut (saturait
    le lien 19200 bauds sous forte charge), auto-reparation radio
    (isChipConnected + reinit), heartbeat STATUS:radioOK= vers le Mega,
    PA_LOW temporaire pour diagnostic de banc.
    - megaf.ino : ALIVE: corrige (radioOK= manquant depuis le passage au pont,
    cassait la detection de redemarrage cote PC), compteur d'ignores non-
    bloquant au lieu d'un print par buzz ignore, wdt_reset() defensif dans
    les boucles serie, fix de l'animation de validation qui pouvait ecraser
    la couleur de l'equipe gagnante en cas de buzz pendant le clignotement.
    A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
    [buzzer_nano_equipe.ino, buzzer_nano_equipe_burst_sync.ino, buzzer_nano_equipe_test.ino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]
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2026-08-22 Porte le fix ALIVE:/ignored= dans diagnostics/quiz_logger.py
    La copie versionnee (celle compilee en .exe par le workflow) n'avait pas
    encore le fix applique sur la copie de travail locale : regex ALIVE_RE
    qui ne matchait plus depuis le passage au pont RF-Nano (radioOK=
    manquant côté firmware avant le fix megaf.ino de cette session), et
    comptage du champ ignored= desormais envoye en resume plutot qu'en
    lignes IGNORED: individuelles.
    [quiz_logger.py]
2026-08-22 Corrige la creation de Release GitHub (permission contents: write manquante)
    Le token GITHUB_TOKEN par defaut du repo n'a que les permissions en
    lecture -> softprops/action-gh-release echouait avec 403 "Resource not
    accessible by integration" au moment de creer la Release sur un tag v*.
    Les builds Windows/Mac eux-memes reussissaient (verifie sur le run
    v1.1.0), seule la publication finale echouait.
2026-08-30 Profils de projecteurs par-fixture + strobe par equipe + fix broche moteur
    - megaf.ino : QuizConfig passe d'un reglage de canaux DMX unique pour
    tous les projecteurs a un profil par projecteur (FixtureProfile) --
    permet de melanger des modeles differents (RGB simple, lyre utilisee
    pour sa couleur) sans toucher au code. SET_PATCH: prend desormais un
    indice de projecteur. Le strobe a l'annonce du gagnant devient un
    reglage PAR EQUIPE (strobeDureeMs : 0=aucun, -1=continu, >0=duree ms)
    au lieu d'une duree fixe globale, via la nouvelle commande
    SET_STROBE_EQ:. Magic number EEPROM re-bumpe (0xAC -> 0xAE).
    - configuration/config_final_30.py : interface mise a jour en
    consequence --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
    [buzzer_nano_equipe.ino, config_final_30.py, megaf.ino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]
2026-09-06 Support des lyres a roue de couleurs + obturateur bloquant
    - megaf.ino : FixtureProfile gagne "mode" (0=RGB continu, 1=roue de
    couleurs -- reutilise offR comme canal unique de la roue) et
    "strobeRepos" (valeur du canal obturateur/strobe HORS strobe -- 0
    normalement, ~255 pour les lyres dont le canal obturateur bloque la
    lumiere en dessous d'un certain seuil). Nouvelle fonction
    couleurVersRoue() : convertit une couleur RGB d'equipe vers la
    position de roue la plus proche par distance euclidienne. SET_PATCH:
    etendu avec 2 champs optionnels (retro-compatible). Magic number
    EEPROM re-bumpe (0xAE -> 0xAF).
    - configuration/config_final_30.py : menu "Mode couleur" et champ
    "Valeur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
    [config_final_30.py, megaf.ino, test_emetteur_bouton.ino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]
2026-09-07 Ajoute la console web (config + animateur) et les couleurs d'affichage cote Quiz Board
    - Nouveau dossier web/ (index.html, style.css, script.js separes) : configuration
    DMX par projecteur, console animateur (buzz, chrono, valider/refuser, podium,
    affichage public), import de questions Excel/CSV, import/export JSON de la
    configuration. Backend ESP32 pas encore branche (bouton "Synchroniser" en mock).
    - interface_30eq.py : couleurs d'affichage par equipe (une ou plusieurs, saisies
    par l'animateur), import optionnel en lecture seule des couleurs DMX reelles
    depuis config_quiz_pro.json pour reference visuelle. Purement cosmetique :
    aucun effet sur le patch DMX ni sur la communication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
    [interface_30eq.py]
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2026-09-07 web: plafonne a 30 equipes et rend le bandeau de buzz collant
    - Bouton "Ajouter une equipe" desactive et compteur affiche au-dela de
    30 equipes (aligne sur la limite MAX_TEAMS du Quiz Board Python) ;
    l'import JSON tronque aussi a 30 par securite.
    - Le bandeau "equipe en ecoute" (Valider/Refuser) reste colle juste
    sous l'en-tete en scrollant, pour rester atteignable sur mobile meme
    avec une longue grille d'equipes.
    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
2026-09-07 web: permet d'ajouter/retirer des equipes depuis la page Animateur
    Certains deploiements separent les roles : l'installateur configure le
    patch DMX sur la page Configuration, mais l'animateur (client final) n'a
    souvent acces qu'a la page Animateur, sans synchronisation entre les deux.
    L'animateur peut donc desormais regler lui-meme le nombre d'equipes (comme
    il pouvait deja saisir leurs couleurs), sans jamais toucher a la config DMX.
    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
2026-09-16 web: conformite hors-ligne, theme clair/sombre, ergonomie, sons client
    - Retire les dependances CDN (Google Fonts + lib Excel) qui cassaient
    l'usage hors-ligne exige par le cahier des charges : la lib xlsx est
    desormais vendue en local (web/vendor/), plus de police externe.
    - Ajoute un theme clair/sombre (variables CSS, toggle injecte, persistant),
    sans y toucher sur public.html qui reste volontairement sombre.
    - config.js : le bouton "Synchroniser la Mega" affichait un faux succes
    simule (setTimeout + logs bidons) sans jamais verifier la vraie reponse
    du Mega. Ecoute maintenant les vrais evenements CONF:/ERR: relayes par
    l'ESP32, avec timeout explicite si rien ne revient.
    - Remp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
2026-09-16 esp32: architecture de secours ESP-NOW pour equipes/animateur
    Le hub (esp32_bridge_server.ino) ecoute desormais nRF24 ET ESP-NOW en
    meme temps, sans rien recompiler pour changer de transport : si un
    boitier Nano+nRF24 pose probleme sur site (historique de fiabilite deja
    documente dans ce projet), esp32_buzzer_equipe.ino / esp32_animateur.ino
    permettent de le remplacer individuellement par un ESP32.
    Meme message RadioMsg{kind,value,seq} sur les deux transports, meme
    dedoublonnage par seq, meme fenetre d'arbitrage de 50ms (traiterMessageRadio()
    partagee). Le canal Wi-Fi est fixe (ESPNOW_WIFI_CHANNEL) car ESP-NOW l'exige ;
    le callback de reception ESP-NOW ne fait qu'empiler dans une file, vide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
    [esp32_animateur.ino, esp32_bridge_server.ino, esp32_buzzer_equipe.ino]
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2026-09-16 docs: ajoute le guide client (televersement, Wi-Fi, limite equipes)
    Couvre le televersement de chaque carte du systeme (Mega, ESP32 hub,
    RF-Nano, buzzers equipe, animateur, nano son, et les versions ESP32 de
    secours), la connexion Wi-Fi (SSID/mdp/IP/mDNS), le plafond reel de
    30 equipes (dimensionnement des tableaux sur toutes les cartes a la
    fois, 32 au maximum absolu cote nano son) et un tableau de depannage.
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2026-09-17 docs: precise la carte ESP32 hub reellement commandee (DevKit V1, FT232)
    Le client a commande la carte pour le hub regie : ESP32 DevKit V1, puce
    USB-serie FT232, 30 broches, micro-USB. Documente ce choix concret dans
    le header du firmware et les deux guides, et corrige le pilote a
    installer en cas de port invisible : FTDI VCP pour cette carte, pas
    CP210x/CH340 (mentionnes avant comme cas generique le plus frequent,
    mais ce n'est pas la puce de cette carte precise). Cote equipe : pas
    encore commande, rien a documenter la pour l'instant.
    [esp32_bridge_server.ino]
2026-09-17 hardware: BOM buzzer equipe (Nano+nRF24 / ESP32) et boitier 3D parametrique
    docs/BOM_BUZZER_EQUIPE.md : composants et brochage des deux cartes buzzer
    (Nano+nRF24 principale, ESP32/ESP-NOW de secours), bloc alimentation commun
    (charge+protection+boost USB-C, coupure automatique batterie faible),
    module vibreur a 3 broches IN/VCC/GND (pas de transistor de commande a
    ajouter, deja integre au module). Capacite batterie dimensionnee pour
    4-6h d'autonomie : 500-600 mAh (Nano) vs 1000-1200 mAh (ESP32, Wi-Fi plus
    gourmand). Carte hub regie confirmee (ESP32 DevKit V1, FT232) documentee
    en meme temps ; carte ESP32 equipe encore au stade candidat (AliExpress,
    CH340C, pas commandee).
    hardware/boitier_b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
    [boitier_buzzer_equipe.scad]
2026-09-17 hardware: schema KiCad de depart pour le buzzer Nano+nRF24, valide par ERC
    hardware/kicad_buzzer_nano/buzzer_equipe_nano.kicad_sch : genere a partir
    du BOM (docs/BOM_BUZZER_EQUIPE.md), 8 composants / 12 nets, verifie avec
    un vrai KiCad (kicad-cli sch erc, snap, sans acces root) plutot que du
    texte S-expression non teste.
    Debogage significatif pour y arriver : le format schematique KiCad exige
    que les symboles embarques dans lib_symbols soient nommes avec leur id
    complet "Bibliotheque:Symbole" (pas le nom nu de la bibliotheque source),
    et la structure d'instance de symbole differe entre les versions de
    fichier KiCad 9 et 10 (champs body_style/in_pos_files/fields_autoplaced/
    show_name/do_not_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
    [buzzer_equipe_nano.kicad_sch]
2026-09-17 hardware: schema KiCad de depart pour le buzzer ESP32 (secours), meme methode
    hardware/kicad_buzzer_esp32/buzzer_equipe_esp32.kicad_sch : meme generateur
    et meme validation reelle (kicad-cli sch erc) que la variante Nano. 6
    composants, 6 nets. Pas de symbole KiCad standard pour la carte exacte
    commandee (trop de variantes de brochage ESP32 DevKit selon fabricant) --
    U1 represente uniquement les 4 signaux reellement cables sur ce PCB
    (GPIO4 bouton, GPIO13 vibreur, 5V, GND), pas les ~30 broches physiques.
    GPIO2 (LED embarquee) omis : interne au module, rien a router ici.
    Verification supplementaire faite sur l'ERC du VRAI projet quizkicad/mega
    (fait a la main dans KiCad, pas genere) : il rele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
    [buzzer_equipe_esp32.kicad_sch]
2026-09-17 hardware: boitier en deux etages demontables, dimensions ESP32 confirmees
    Refonte de boitier_buzzer_equipe.scad : PCB+modules (sur connecteurs
    femelles, pas soudes directement) et batterie n'etaient cote a cote dans
    un seul compartiment -- passe a deux etages empiles, chacun demontable
    independamment (couvercle superieur avec le bouton pour l'etage PCB,
    trappe separee pour l'etage batterie), avec une etagere interne et une
    fente de passage de cables entre les deux. Permet de changer/recharger
    la batterie sans demonter l'electronique du dessus.
    Dimensions ESP32-DevKitC-32 (variante equipe) corrigees avec les
    specs CONFIRMEES de la fiche produit du modele envisage (52x28mm,
    CH340C, USB-C) au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
    [boitier_buzzer_equipe.scad]
2026-09-17 hardware: 3e schema KiCad -- adaptateur regie/hub Mega+ESP32+nRF24
    hardware/kicad_regie_hub/regie_hub_mega_esp32.kicad_sch : meme methode
    que les deux cartes buzzer (genere, verifie par kicad-cli sch erc reel).
    11 composants, 14 nets.
    Carte adaptateur, PAS un shield Mega complet (le shield DMX quizkicad/mega,
    projet separe, s'empile deja directement sur la Mega) : relie a la Mega
    par 6 fils seulement (2 liens serie + 5V + GND). Pas de batterie -- le
    systeme est alimente secteur via le regulateur deja present sur la Mega,
    qui alimente aussi cette carte.
    Deux choix de conception delibere, expliques dans le README :
    - Pont diviseur 1k/2k (pas de module convertisseur de niveau logique
    dedie)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
    [regie_hub_mega_esp32.kicad_sch]
2026-09-18 hardware: placement PCB + reperes de serigraphie pour les 3 cartes
    Empreintes placees et etiquettes de soudage (repere + brochage) pour les
    cartes buzzer Nano, buzzer ESP32 et regie/hub, validees avec kicad-cli pcb
    drc (seuls avertissements restants: lib_footprint_mismatch, cosmetique).
    Routage des pistes volontairement non genere, a faire a la main dans KiCad.
    [buzzer_equipe_esp32.kicad_pcb, buzzer_equipe_nano.kicad_pcb, regie_hub_mega_esp32.kicad_pcb]
2026-09-18 hardware: pistes routees sur les 3 cartes (Freerouting + kicad-cli pcb drc)
    Autoroutage headless via Freerouting (pcbnew.ExportSpecctraDSN -> java -jar
    freerouting.jar -> pcbnew.ImportSpecctraSES), pas un routage devine a la
    main. Resultat verifie avec kicad-cli pcb drc reel sur les 3 cartes: 0
    violation de clearance, 0 element non connecte. Seuls avertissements
    restants: lib_footprint_mismatch (cosmetique) et quelques track_dangling
    (residu mineur d'autorouter, a nettoyer dans KiCad, sans impact electrique).
    [buzzer_equipe_esp32.kicad_pcb, buzzer_equipe_nano.kicad_pcb, regie_hub_mega_esp32.kicad_pcb]
2026-09-18 hardware: nettoyage track_dangling + C3 rapproche de J_NRF sur le hub
    Nano: 2 troncons de piste dupliques/morts (net NRF_SCK) identifies et
    supprimes via script pcbnew, ne menaient a aucune pastille -- DRC propre
    (0 track_dangling, 0 non connecte, seul lib_footprint_mismatch cosmetique
    reste).
    Hub: le nRF24 (J_NRF) et son condensateur de decouplage dedie (C3) etaient
    a 25mm -- trop loin pour un decouplage propre a 2,4GHz. C3 repositionne a
    12mm de J_NRF, carte entierement re-routee (Freerouting), puis 2 nouveaux
    track_dangling (net VCC_5V_MEGA) nettoyes de la meme facon. DRC final: 0
    violation de clearance, 0 non connecte, 0 track_dangling.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
    [buzzer_equipe_nano.kicad_pcb, regie_hub_mega_esp32.kicad_pcb]
2026-09-18 hardware: vrais ports femelles pour les modules (Nano, ESP32 x2) + reroutage
    Remplace les empreintes abstraites/simplifiees par de vraies barrettes
    femelles PinSocket, dimensionnees et brochees pour correspondre aux modules
    physiques reels, sur les 3 cartes:
    - Nano (buzzer equipe): 2x PinSocket_1x15 (A1L/A1R, 30 broches, entraxe
    15,24mm) au lieu de l'empreinte "Nano soude directement" -- numerotation
    verifiee contre la vraie empreinte Module:Arduino_Nano.
    - ESP32 buzzer (secours): 2x PinSocket_1x19 (U1L/U1R, 38 broches, entraxe
    22,86mm) au lieu du connecteur 4 broches abstrait -- brochage GPIO4/
    GPIO13/VIN/GND positionne selon le layout generique 38 broches le plus
    courant (verifi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
    [buzzer_equipe_esp32.kicad_pcb, buzzer_equipe_nano.kicad_pcb, regie_hub_mega_esp32.kicad_pcb]
2026-09-18 hardware: retire la mention "routage a faire a la main" (obsolete)
    Le texte de titre sur la serigraphie des 3 cartes disait encore "ROUTAGE
    DES PISTES A FAIRE A LA MAIN DANS KICAD", ecrit avant que le routage ne
    soit fait via Freerouting. Remplace par une mention correcte ("pistes
    routees (Freerouting), a relire avant fabrication"). Edition de texte
    seule sur les fichiers deja routes -- aucune piste/pastille touchee,
    DRC revalide identique (0 violation de clearance, 0 non connecte).
    [buzzer_equipe_esp32.kicad_pcb, buzzer_equipe_nano.kicad_pcb, regie_hub_mega_esp32.kicad_pcb]
2026-09-18 hardware: titres serigraphie simplifies (retire tout commentaire de process)
    Le titre en haut de chaque carte disait encore des phrases du type "pistes
    routees (Freerouting), a relire avant fabrication" -- du commentaire sur le
    processus de generation, pas quelque chose qui a sa place gravee sur un vrai
    circuit fabrique. Remplace par un simple nom de carte ("BUZZER EQUIPE -
    NANO", "BUZZER EQUIPE - ESP32", "REGIE HUB"). Le bloc BROCHAGE (guide de
    soudage demande explicitement) reste inchange. Edition de texte seule,
    DRC revalide identique sur les 3 cartes.
    [buzzer_equipe_esp32.kicad_pcb, buzzer_equipe_nano.kicad_pcb, regie_hub_mega_esp32.kicad_pcb]
2026-09-18 hardware: corrige VCC/GND nRF24 (inverses) + passe en 2x4 (module PA+LNA)
    En reponse a "le nrf24 c'est sur une ligne ?", verification du brochage
    nRF24 contre 3 sources independantes (components101.com,
    lastminuteengineers.com, doc generale nRF24L01+) : la broche 1 est GND et
    la broche 2 est VCC, pas l'inverse comme c'etait cable jusqu'ici sur J1
    (carte Nano) et J_NRF (carte hub) -- schema ET PCB. Broche 1 = toujours la
    pastille carree sur cette empreinte, coherent avec "GND identifiable par
    son marquage carre" documente pour ce module.
    Le module confirme etant un nRF24L01+PA+LNA (longue portee), son connecteur
    est 2x4 et non 1x8 standard -- empreinte changee vers PinSocket_2x04 sur
    les 2 c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
    [buzzer_equipe_nano.kicad_pcb, buzzer_equipe_nano.kicad_sch, regie_hub_mega_esp32.kicad_pcb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]
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2026-09-18 hardware: cartes retrecies, guide serigraphie retire, keepout sous le nRF24
    3 demandes traitees sur les 3 cartes:
    - Retrait du texte-guide en serigraphie (bloc BROCHAGE) -- n'a plus sa
    place sur un circuit destine a la fabrication reelle. Repere de
    composant standard (A1L, J1, C1...) conserve, paragraphe d'instructions
    retire.
    - Cartes nettement plus compactes: nano 125x145 -> 90x100mm, hub
    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
    [buzzer_equipe_esp32.kicad_pcb, buzzer_equipe_nano.kicad_pcb, regie_hub_mega_esp32.kicad_pcb]
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2026-09-18 hardware: BT1 en vrai connecteur JST-PH (pas de simples pastilles)
    Repond a "comment on va s'y prendre pour connecter le systeme de charge":
    les batteries LiPo standards arrivent avec une prise JST-PH FEMELLE deja
    sertie sur leurs fils -- BT1 portait jusqu'ici de simples pastilles
    (recemment passees en CMS), ce qui aurait oblige a couper la prise
    d'origine pour souder des fils nus. Remplace par le vrai connecteur MALE
    correspondant (JST_PH_B2B-PH-K), deja recommande dans le BOM
    (docs/BOM_BUZZER_EQUIPE.md: "Connecteur batterie JST-PH 2 points") mais
    jamais implemente comme tel sur le PCB.
    Volontairement laisse TRAVERSANT (pas de variante CMS) contrairement aux
    autres petits connecteurs conve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
    [buzzer_equipe_esp32.kicad_pcb, buzzer_equipe_nano.kicad_pcb]
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2026-09-20 firmware: DMX sur Serial0 et lien config ESP32 sur Mega Serial1
    Le shield DMX est cable sur Serial0 mais la lib personnalisee partait par
    defaut sur Serial3 (conflit avec PC_SERIAL). DMX_FORCE_USART0 corrige ca.
    Serial1, libre, devient le lien config ESP32 en parallele du cable PC
    (Serial3) : deux boucles de lecture, statut diffuse sur les deux ports.
    Doc de cablage corrigee (pins 18/19, ancien RX3/TX3 etait inverse).
    [esp32_bridge_server.ino, megaf.ino]
2026-09-20 web: sons personnalises persistes dans IndexedDB et precharges
    Les sons chargeaient en memoire seulement et se perdaient a chaque
    ouverture. Ils sont maintenant sauvegardes sur l'appareil et restaures au
    demarrage ; les elements Audio sont precharges (moins de latence au buzz).
2026-09-20 hardware: carte ESP32 equipe 65x50mm, BOM CSV, libelle J_MEGA hub
    ESP32 equipe reduite a 65x50mm (U1L/U1R et J2/J3 pivotes a 90 degres),
    reroutee, DRC sans clearance ni connexion manquante. Gerbers regeneres.
    Fichiers BOM CSV ajoutes pour les 3 cartes. Hub : libelle J_MEGA
    TX1/RX1 (pins 18/19) au lieu de TX3/RX3, sans changement de routage.
    [buzzer_equipe_esp32-B_Cu.gbl, buzzer_equipe_esp32-B_Mask.gbs, buzzer_equipe_esp32-B_Paste.gbp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]
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2026-09-20 config: lecture de la config depuis la Mega (GET_CONFIG), Python <-> appli web
    La Mega devient la reference commune : le logiciel Python et l'appli web
    y ecrivent deja (SET_* + SAVE_CONFIG), ils peuvent maintenant la relire.
    Envoi non bloquant (une ligne par loop, seulement si les deux ports ont de
    la place), refuse pendant une manche. ESP32 accumule le dump et le diffuse
    en un seul message WebSocket. Bouton "Lire depuis la Mega" dans config.html
    et dans config_final_30.py (sauvegarde .bak de l'ancienne config PC).
    Corrige aussi le commentaire du firmware ESP32 : la carte recue a une puce
    CP2102, pas FT232.
    [config_final_30.py, esp32_bridge_server.ino, megaf.ino]
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2026-09-20 megaf: interrupteur DMX_SUR_SERIAL0, commentaire corrige
    Le commentaire precedent s'appuyait a tort sur le projet KiCad
    quizkicad/mega, qui ne contient que les connecteurs de la Mega et pas le
    circuit DMX. Le cablage exact du shield n'est pas confirme : le define
    devient un interrupteur documente (1 = Serial0, 0 = choix de la lib).
    [megaf.ino]
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2026-09-20 megaf: retire DMX_FORCE_USART0 (sans effet), commentaire DMX corrige
    Le define n'a aucun effet avec la lib DMXSerial standard (binaires
    identiques) et la lib modifiee de src/ (USART3) ne se lie pas avec ce
    sketch (conflit avec Serial3). Le commentaire rappelle que les cavaliers
    du shield DMX doivent etre remis apres televersement.
    [megaf.ino]
